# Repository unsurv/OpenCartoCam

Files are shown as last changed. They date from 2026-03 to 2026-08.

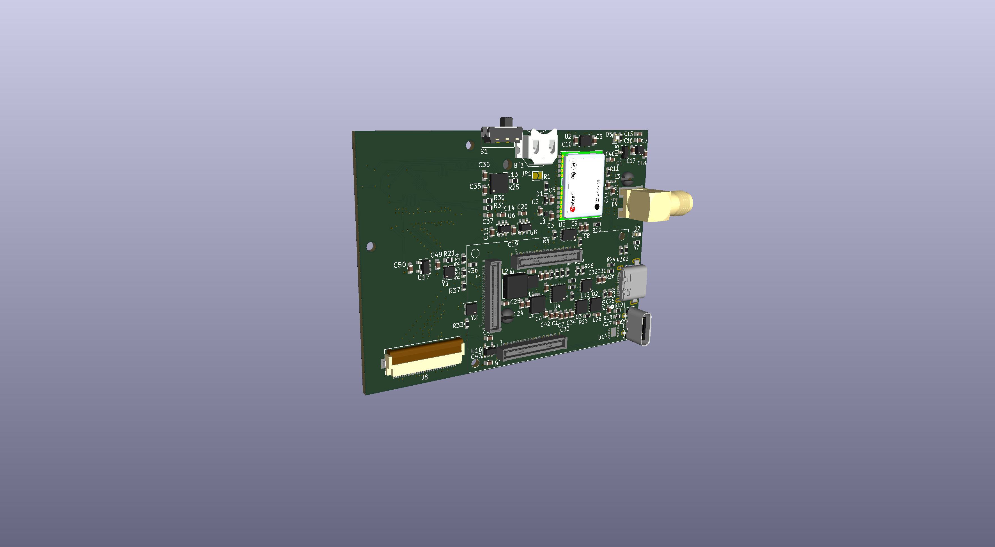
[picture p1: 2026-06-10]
docs/_static/mainboard_only.png

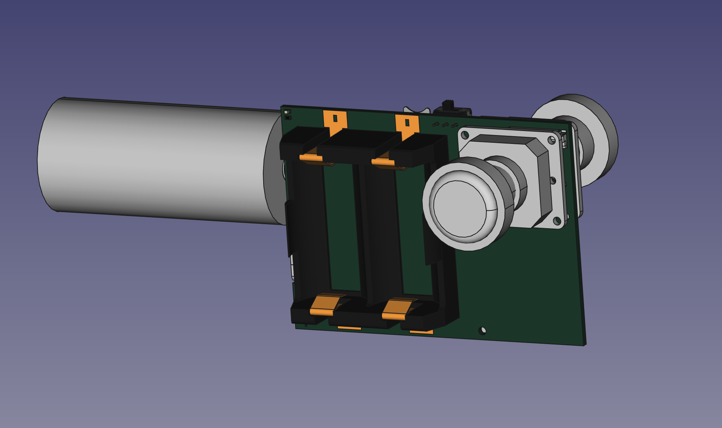
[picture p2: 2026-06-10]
docs/_static/3D_preview_back.PNG

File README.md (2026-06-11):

# OpenCartoCam

## What is it

OpenCartoCam is an open source 360-degree camera that leverages edge computing to support cartographing the world. Equipped with precise positioning systems and hardware-accelerated object detection, it enables semi-automatic mapping and categorization while maintaining a compact form factor.

## Current status

Status **in development**

- decided on SolidRun [Hailo-15-SOM](https://www.solid-run.com/hailo-15-som/) as main compute unit.
- custom designed carrier board with necessary power structure and external connectors (USB, Micro SD, SMA)
- ublox NEO-F10 GNSS receiver (L1 + L5) with passive omnidirectional antenna for good value urban performance.
- two IMX 678 (M12 lens mount) sensors with kernel support
- dead reckoning
- off the shelf [Insta360 Ace Pro 2 battery](https://store.insta360.com/en/product/ace-pro-2-battery)

## TODOs

- board evaluation
- Yocto software integration
- Sensor integration (Gyro, GNSS)

## Funding

This project is funded through [NGI0 Commons Fund](https://nlnet.nl/commonsfund), a fund established by [NLnet](https://nlnet.nl) with financial support from the European Commission's [Next Generation Internet](https://ngi.eu) program. Learn more at the [NLnet project page](https://nlnet.nl/project/OpenCartoCam).

[NLnet foundation logo](https://nlnet.nl)
[NGI Zero Logo](https://nlnet.nl/commonsfund)

## Licences

GNSS schematic partially based on [SparkFun NEO-F10N](https://github.com/sparkfun/SparkFun_u-blox_NEO-F10N)
by SparkFun Electronics, licensed under [CC BY-SA 4.0](https://creativecommons.org/licenses/by-sa/4.0/).

Modifications by Martin. Schematic is also licensed under CC BY-SA 4.0.

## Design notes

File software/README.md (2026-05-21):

# Software

## Object detection targets

- traffic signs
- traffic lights
- defib signs
- streetlamps
- zebra crossings
- manholes
- surveillance cameras

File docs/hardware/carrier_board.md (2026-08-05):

# Carrier board

The main hardware of this project is a custom carrier board for the [HAILO-15 SOM](https://www.solid-run.com/hailo-15-som/) from SolidRun. With just 47 mm x 30 mm in size it is a great basis for a custom 360° camera.

The carrier board offers the following features:

- board to board Hirose DF40 connectors matching those from the SOM
- two USB-C receptables one for USB PD 9V3A and the other exposing a shell to the HAILO-SOM.
- [ublox F10-N](https://www.u-blox.com/en/product/neo-f10n-module) multiband GNSS receiver with L5 reception to improve urban performance.
- battery and system power management (see[power management](./power.md))

``` {image} _static/3D_preview_front.PNG

```

``` {image} _static/3D_preview_back.PNG

```

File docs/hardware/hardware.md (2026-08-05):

# Hardware

``` {toctree}
:glob:

./*
```

All hardware is developed using open toolchains:

- PCB -> KiCad
- 3D design -> FreeCAD

## Images

``` {image} _static/mainboard_only.png

```

``` {image} _static/schematic.PNG

```

``` {image} _static/PCB_view.PNG

```

``` {image} _static/3D_preview_front.PNG

```

``` {image} _static/3D_preview_back.PNG

```

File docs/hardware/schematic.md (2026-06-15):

# PCB Schematic

The schematic can be found [here](https://github.com/unsurv/OpenCartoCam/tree/main/hardware/pcb/board/mainboard) as part of a KiCad project.

[Schematic PDF](./_static/mainboard.pdf)

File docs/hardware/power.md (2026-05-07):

# Power management

## Battery management

## 5V rail

## 3V3 rail

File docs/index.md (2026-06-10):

# OpenCartoCam

``` {toctree}
:hidden:
:glob:

hardware/hardware
grant/grant
```

## What is it

OpenCartoCam is an open source 360-degree camera that leverages edge computing to support cartographing the world. Equipped with precise positioning systems and hardware-accelerated object detection, it enables semi-automatic mapping and categorization while maintaining a compact form factor.

## Current status

Status **in development**

- decided on SolidRun [Hailo-15-SOM](https://www.solid-run.com/hailo-15-som/) as main compute unit.
- custom designed carrier board with necessary power structure and external connectors (USB, Micro SD, SMA)
- ublox NEO-F10 GNSS receiver (L1 + L5) with passive omnidirectional antenna for good value urban performance.
- two IMX 678 (M12 lens mount) sensors with kernel support
- dead reckoning
- off the shelf [Insta360 Ace Pro 2 battery](https://store.insta360.com/en/product/ace-pro-2-battery)

## TODOs

- carrier board evaluation
- Yocto software integration
- Sensor integration (Gyro, GNSS)
- find blade battery connector with 2 mm pitch and create daughterboard for slim battery fit

## Acknoledgements

This project is supported by [NLnet NGI0 Commons Fund](https://nlnet.nl/project/OpenCartoCam/)

## Licences

GNSS schematic partially based on [SparkFun NEO-F10N](https://github.com/sparkfun/SparkFun_u-blox_NEO-F10N)
by SparkFun Electronics, licensed under [CC BY-SA 4.0](https://creativecommons.org/licenses/by-sa/4.0/).

Modifications by Martin. Schematic is also licensed under CC BY-SA 4.0.

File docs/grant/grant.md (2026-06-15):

# nlnet grant

Initial work of this project has been supported by a grant from [nlnet](https://nlnet.nl/project/OpenCartoCam/)

This documents is used to track milestones.

## Hardware Development

Development of the physical systems, from PCB design to camera integration and sensor support, including 3D prototyping.

- buy devboard & setting it up (expense + work) ✅
  - bought [HAILO-15 dev board](https://www.solid-run.com/embedded-industrial-iot/hummingboard-hailo-15-aiot-sbc/)
- Daughterboard connection present ✅
  - see [img](#carrier-board-connection)
- Power management ✅
  - see lefthand side of [schematic](#schematic)
  - see center area of [PCB](#pcb-view)
- Battery support added ✅
  - see [PCB backside](#3d-preview-back)
  - see [BQ25606 schematic](#schematic)
- External connections (USB, antenna, camera) ✅
  - see [3D view front](#3d-preview-front)
  - see relevant parts of the [schematic](#schematic)
- PCB outline defined ✅
  - see [3D](#3d-preview-front)
- Camera connections ✅
  - see bottom right for [FPC connections](#schematic)
- Prototype assembly
- Debug connections ✅
  - see testpoints [schematic](#schematic)
  - see secondary [USB receptable](#schematic) for shell access
- SD card present ✅
  - bottom right in [schematic](#schematic)
  - see [PCB backside](#3d-preview-back)
- IMX219 driver support on development board
- Customized Yocto Linux running on dev board
- Prototype 3D case
- Sensor (GPS + gyroscope) integration
- Hardware docs
- Hardware expenses (expenses; various parts + PCB production)

## Software Development

Core software implementation, including dewarping, sensor/software integration, and privacy-aware mapping output.

- Dewarp method established
- Hardware-accelerated model running  
- Software sensor integration  
- Privacy features (face, license plate blurring)  
- Output generation
- Browser-based evaluation software developed
- OSM integration
- Custom object detection model trained and integrated
- Software docs

## Supporting Activities

Tasks supporting data collection, preparation, and documentation.

- Gathering images for retraining (work + travelling expenses)
- Image preparation (binning, labelling, scaling)

## Final release

- Beta release
- Process feedback from security audit and accessibility scan
- Final release with updated documentation

## Images

### carrier board connection

``` {image} ./_static/DF40.PNG

```

### schematic

``` {image} ../hardware/_static/schematic.PNG

```

### PCB view

``` {image} ../hardware/_static/PCB_view.PNG

```

## 3D preview front

``` {image} ../hardware/_static/3D_preview_front.PNG

```

## 3D preview back

``` {image} ../hardware/_static/3D_preview_back.PNG

```

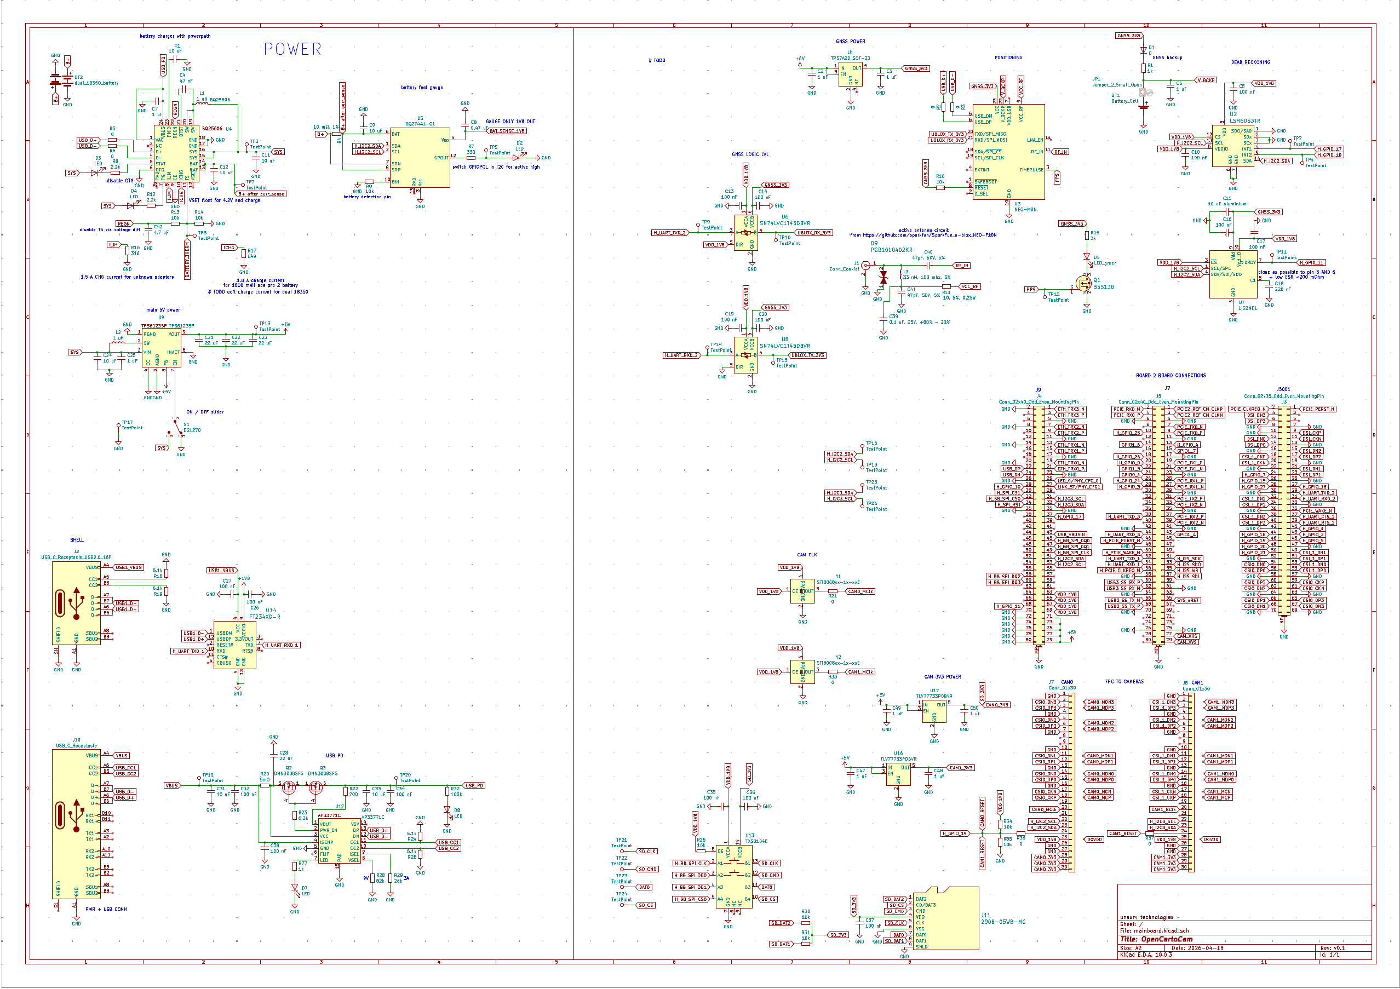
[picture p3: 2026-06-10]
docs/_static/schematic.PNG

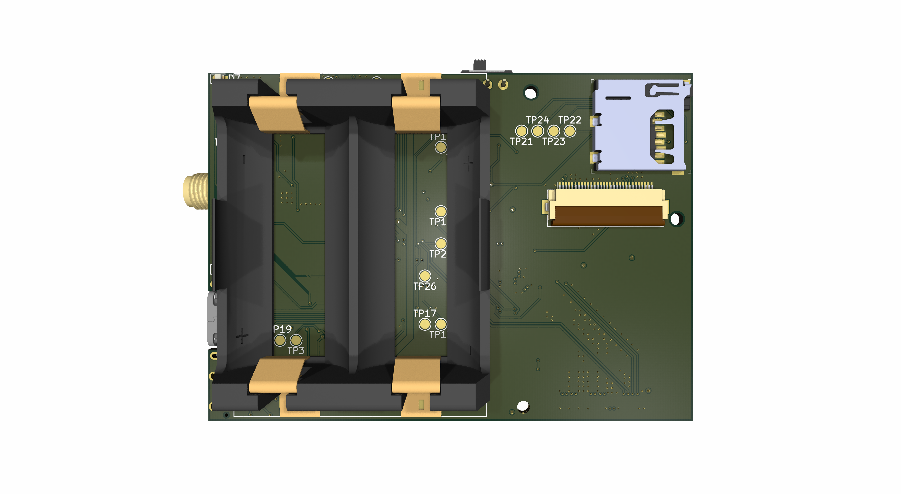
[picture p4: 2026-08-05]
hardware/pcb/board/mainboard/mainboard_raytracing_back.png

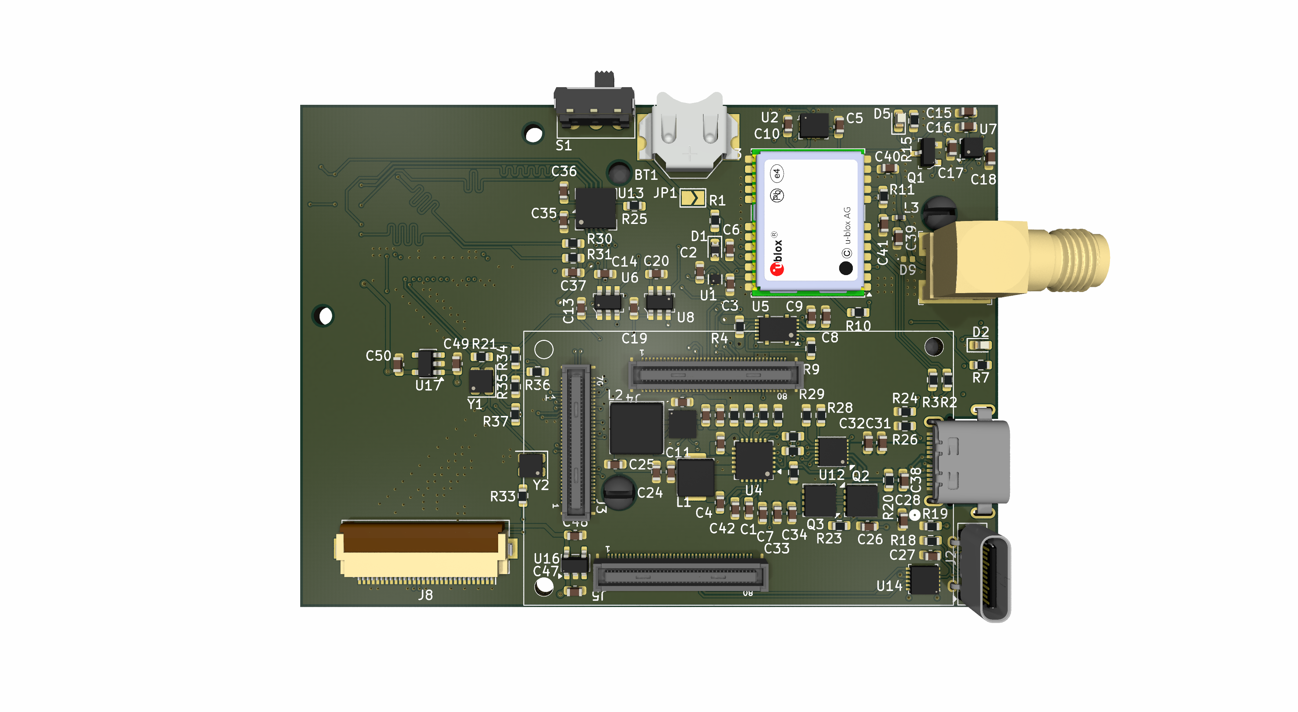
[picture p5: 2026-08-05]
hardware/pcb/board/mainboard/mainboard_raytracing.png

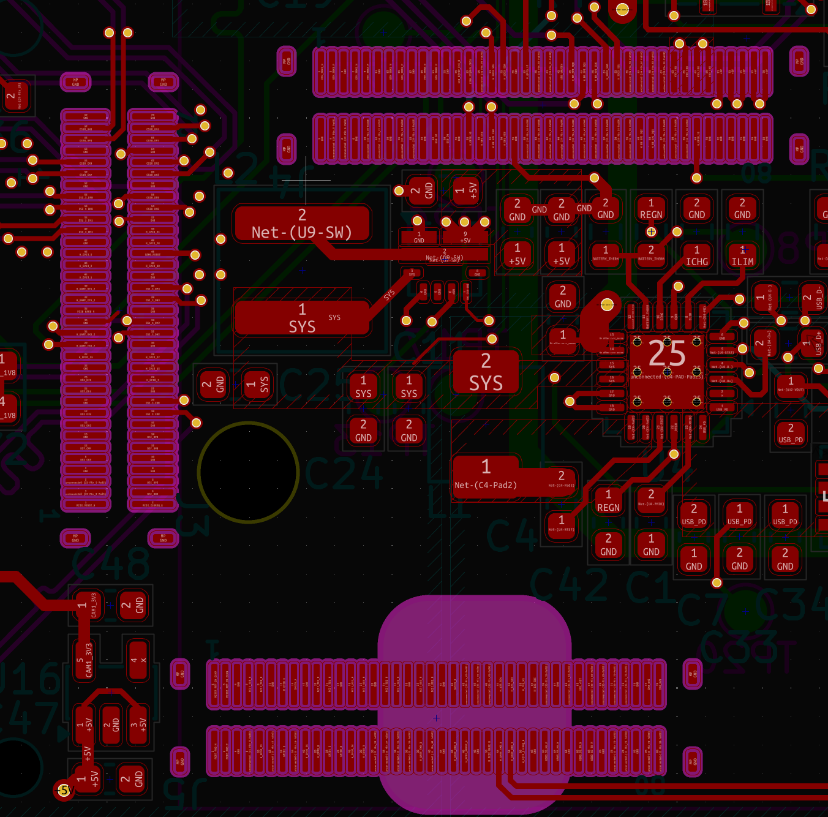
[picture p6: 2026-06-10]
docs/grant/_static/DF40.PNG

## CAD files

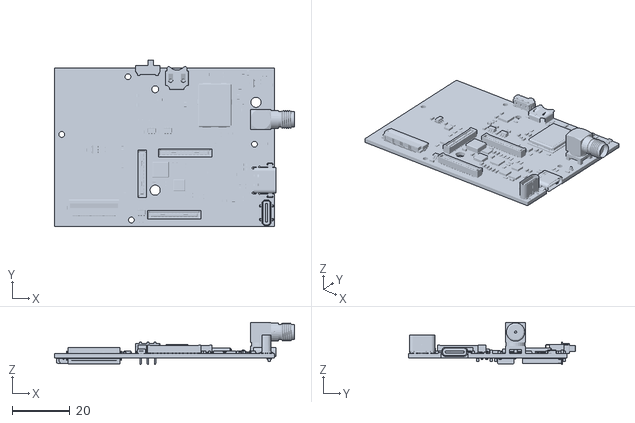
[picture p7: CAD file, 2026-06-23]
hardware/3d/camera/camera-mainboard.stl
83.3 x 57.8 x 14.8

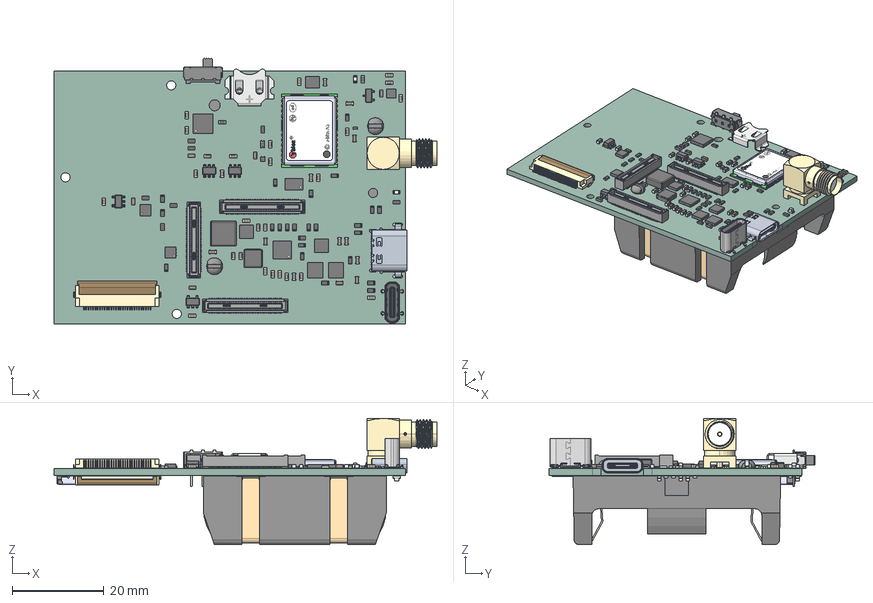
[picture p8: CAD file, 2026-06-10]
hardware/pcb/board/mainboard/mainboard.step
83.3 x 57.8 x 27.4 mm
R_0603_1608Metric x 37
DFN-12-1EP_3x3mm_P0.45mm_EP1.65x2.38mm
C_0603_1608Metric x 44
SOT-23-5 x 2
TDFN_6_1EP_25x25mm_P065mm_EP13x2mm x 2
L_0402_1005Metric
lock x 2
pins x 2
DF40HC(3.0)-80DS-0.4V x 2
LED_0603_1608Metric x 6
SOT-23-3
L_Changjiang_FNR4012S
EG1270
Texas_S_PDSO_N12
CASE
SOT-23-6 x 2
CONSMA002-SMD-G
LGA_14_3x25mm_P05mm_LayoutBorder3x4y
Diodes-PowerDI3333-8 x 2
Texas_S_PVQFN_N14
NEO_PCB
Shield_NEO
u-blox_NEO_label
QFN-24-1EP_4x4mm_Pitch0.5mm x 2
DFN_4_1EP_1x1mm_P065mm_EP05x05mm
LGA_12_2x2mm_P05mm
L_Coilcraft_XAL5020-XXX
D_0603
DFN_14_1EP_3x3mm_Pitch04mm
2908-05WB-MG
mainboard_PCB

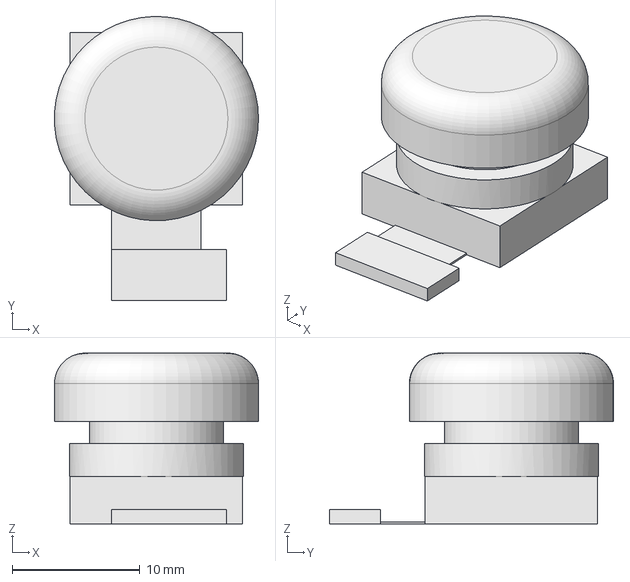
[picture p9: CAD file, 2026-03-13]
hardware/3d/IMX219/IMX219_fisheye.FCStd
16.0 x 22.2 x 13.4 mm

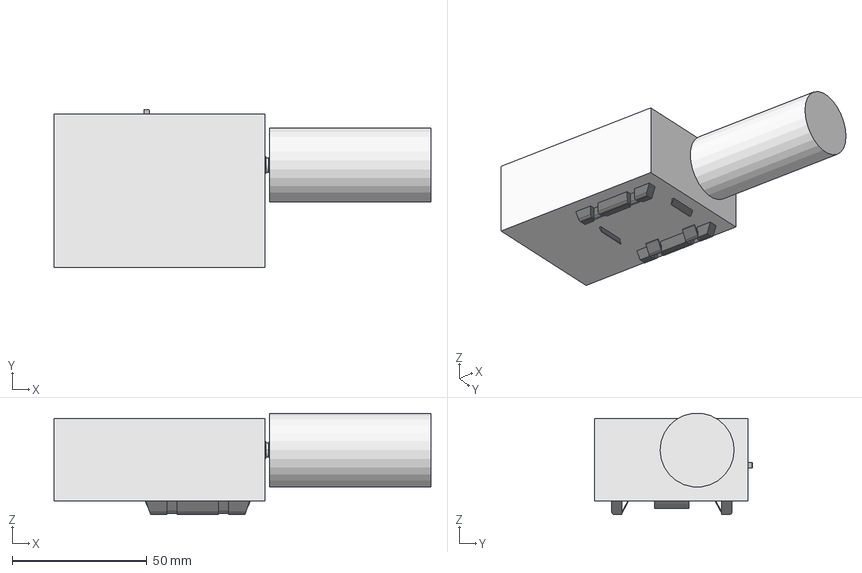
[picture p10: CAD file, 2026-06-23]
hardware/3d/camera/camera.FCStd
140.0 x 58.8 x 37.6 mm
GNSS_helical
HAILO15_SOM
front_case
R_0603_1608Metric
DFN-12-1EP_3x3mm_P0.45mm_EP1.65x2.38mm
C_0603_1608Metric
C_0603_1608Metric002
SOT-23-5
R_0603_1608Metric002
C_0603_1608Metric004
C_0603_1608Metric006
R_0603_1608Metric004
R_0603_1608Metric006
R_0603_1608Metric008
R_0603_1608Metric010
C_0603_1608Metric008
R_0603_1608Metric012
R_0603_1608Metric014
R_0603_1608Metric016
TDFN_6_1EP_25x25mm_P065mm_EP13x2mm
C_0603_1608Metric010
C_0603_1608Metric012
C_0603_1608Metric014
L_0402_1005Metric
R_0603_1608Metric018
C_0603_1608Metric016
C_0603_1608Metric018
lock
pins
C_0603_1608Metric020
C_0603_1608Metric022
R_0603_1608Metric020
DF40HC(3.0)-80DS-0.4V
LED_0603_1608Metric
C_0603_1608Metric024
C_0603_1608Metric026
R_0603_1608Metric022
SOT-23-3
R_0603_1608Metric024
C_0603_1608Metric028
L_Changjiang_FNR4012S
C_0603_1608Metric030
C_0603_1608Metric032
EG1270
Texas_S_PDSO_N12
R_0603_1608Metric026
C_0603_1608Metric034
C_0603_1608Metric036
C_0603_1608Metric038
CASE
R_0603_1608Metric028
DF40HC(3.0)-80DS-0.4V001
R_0603_1608Metric030
R_0603_1608Metric032
R_0603_1608Metric034
C_0603_1608Metric040
C_0603_1608Metric042
SOT-23-6
C_0603_1608Metric044
R_0603_1608Metric036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

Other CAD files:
hardware/3d/IMX219/IMX219_fisheye.stl

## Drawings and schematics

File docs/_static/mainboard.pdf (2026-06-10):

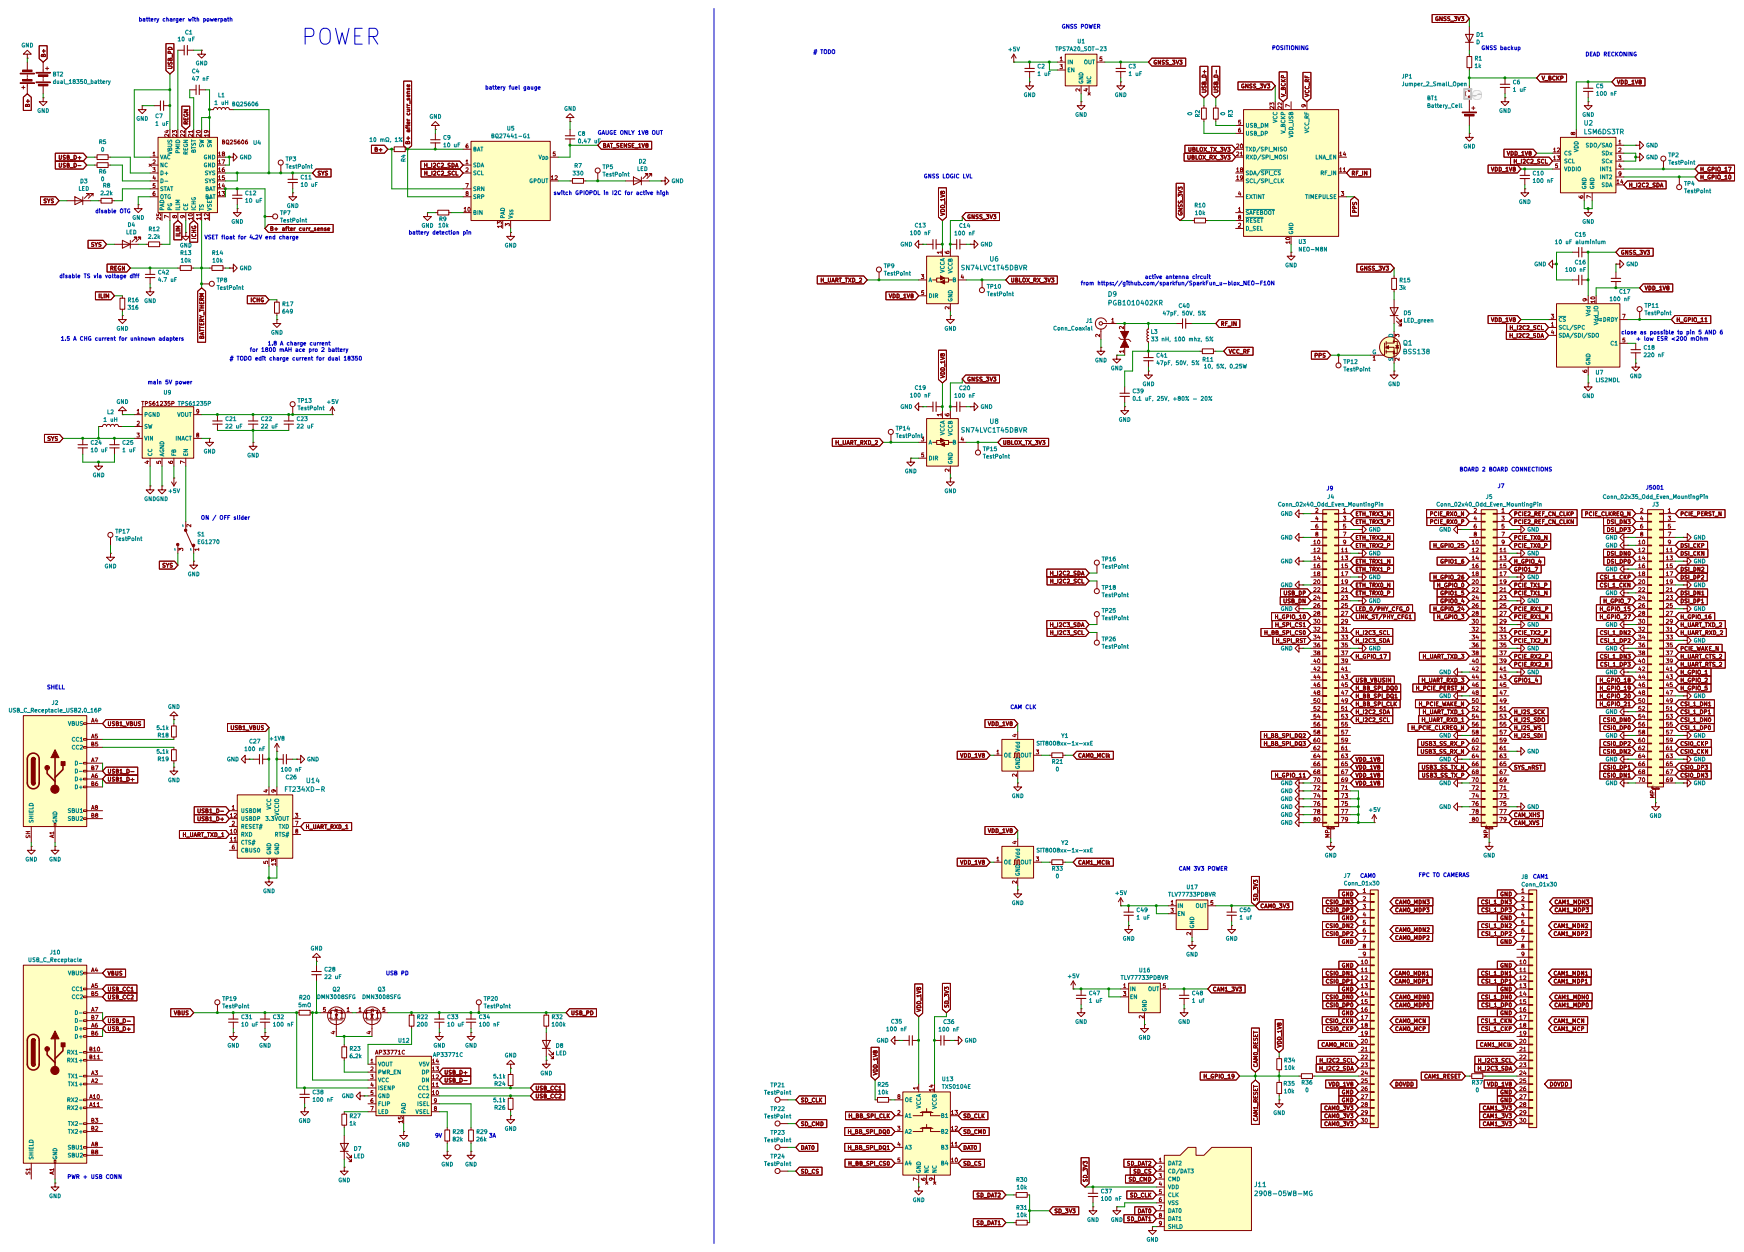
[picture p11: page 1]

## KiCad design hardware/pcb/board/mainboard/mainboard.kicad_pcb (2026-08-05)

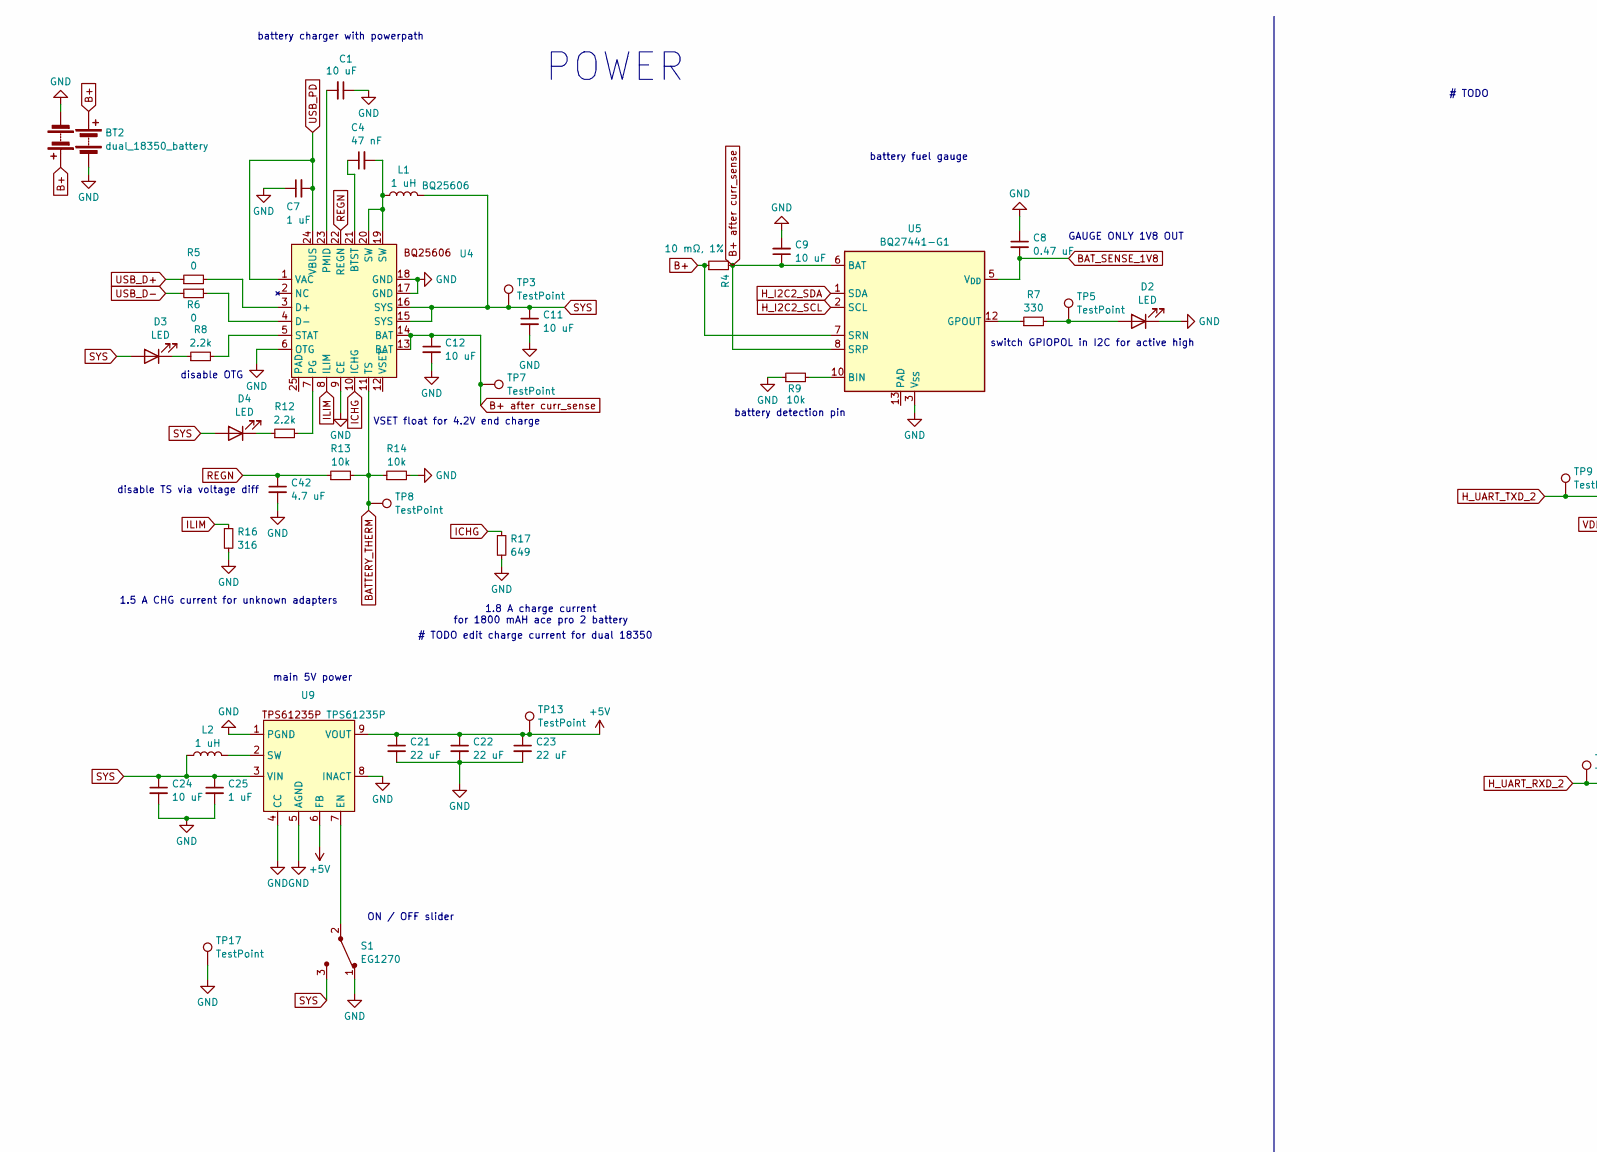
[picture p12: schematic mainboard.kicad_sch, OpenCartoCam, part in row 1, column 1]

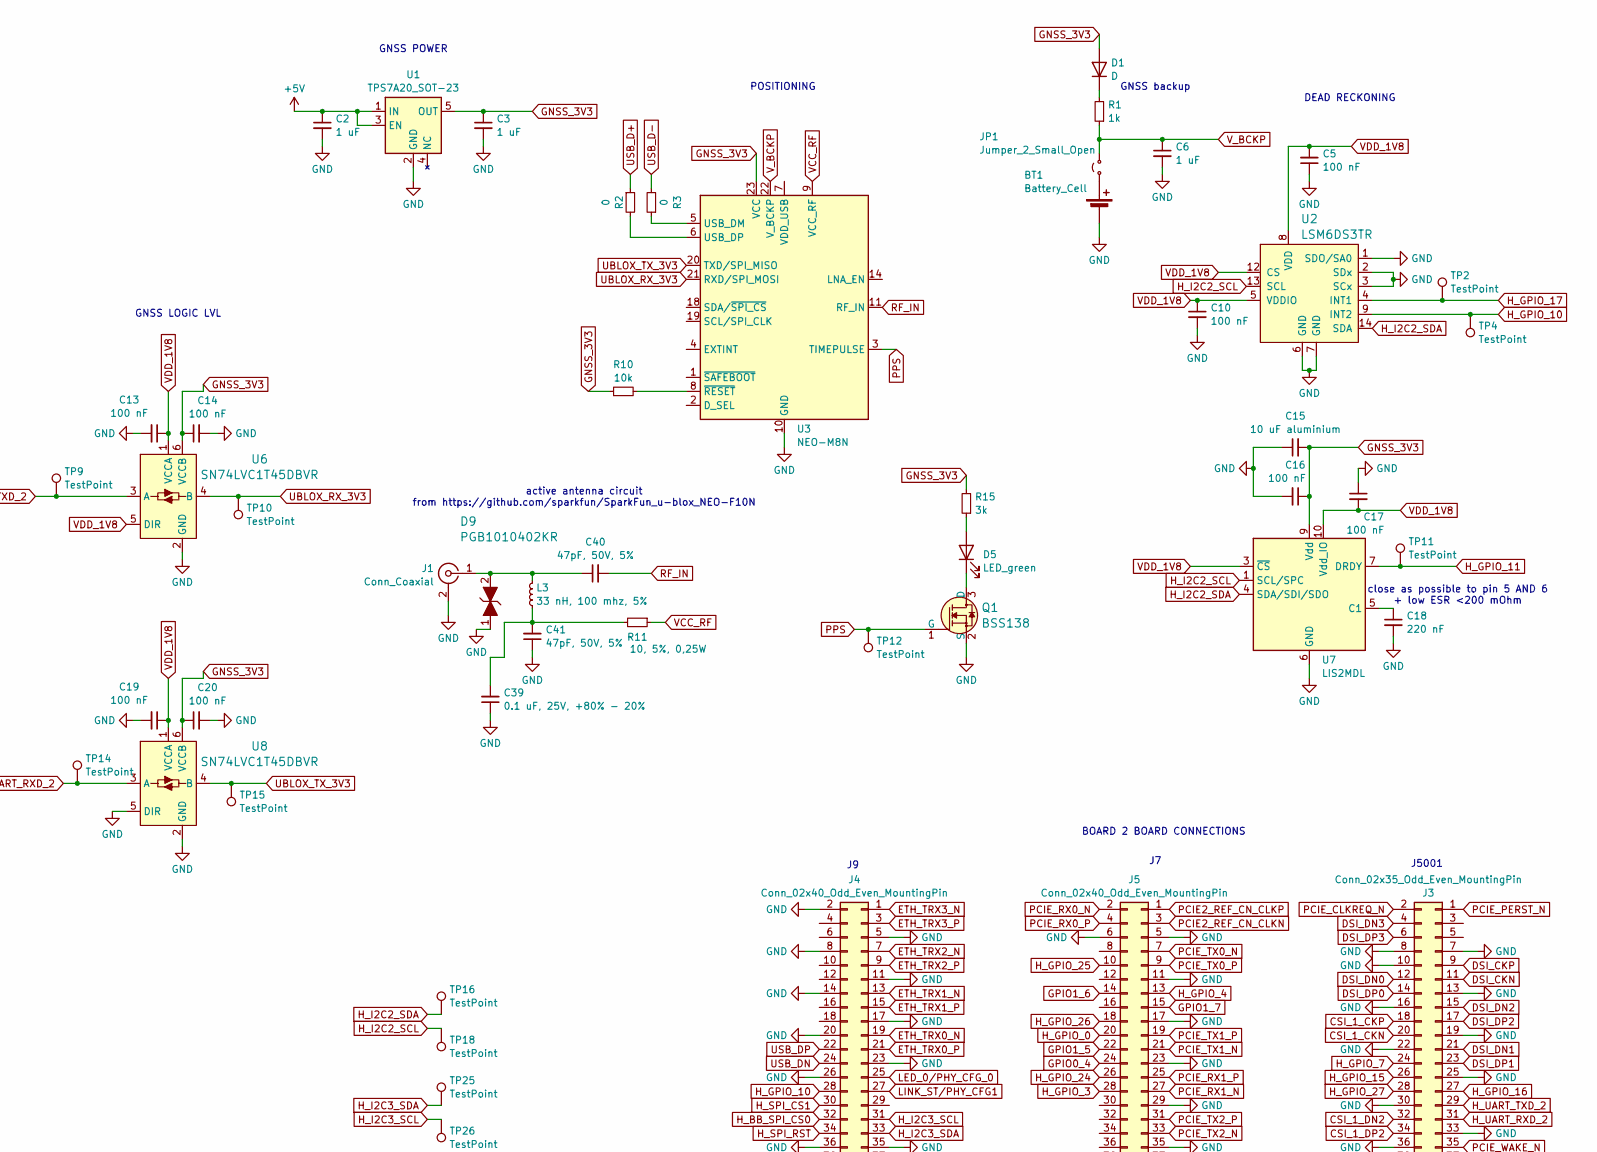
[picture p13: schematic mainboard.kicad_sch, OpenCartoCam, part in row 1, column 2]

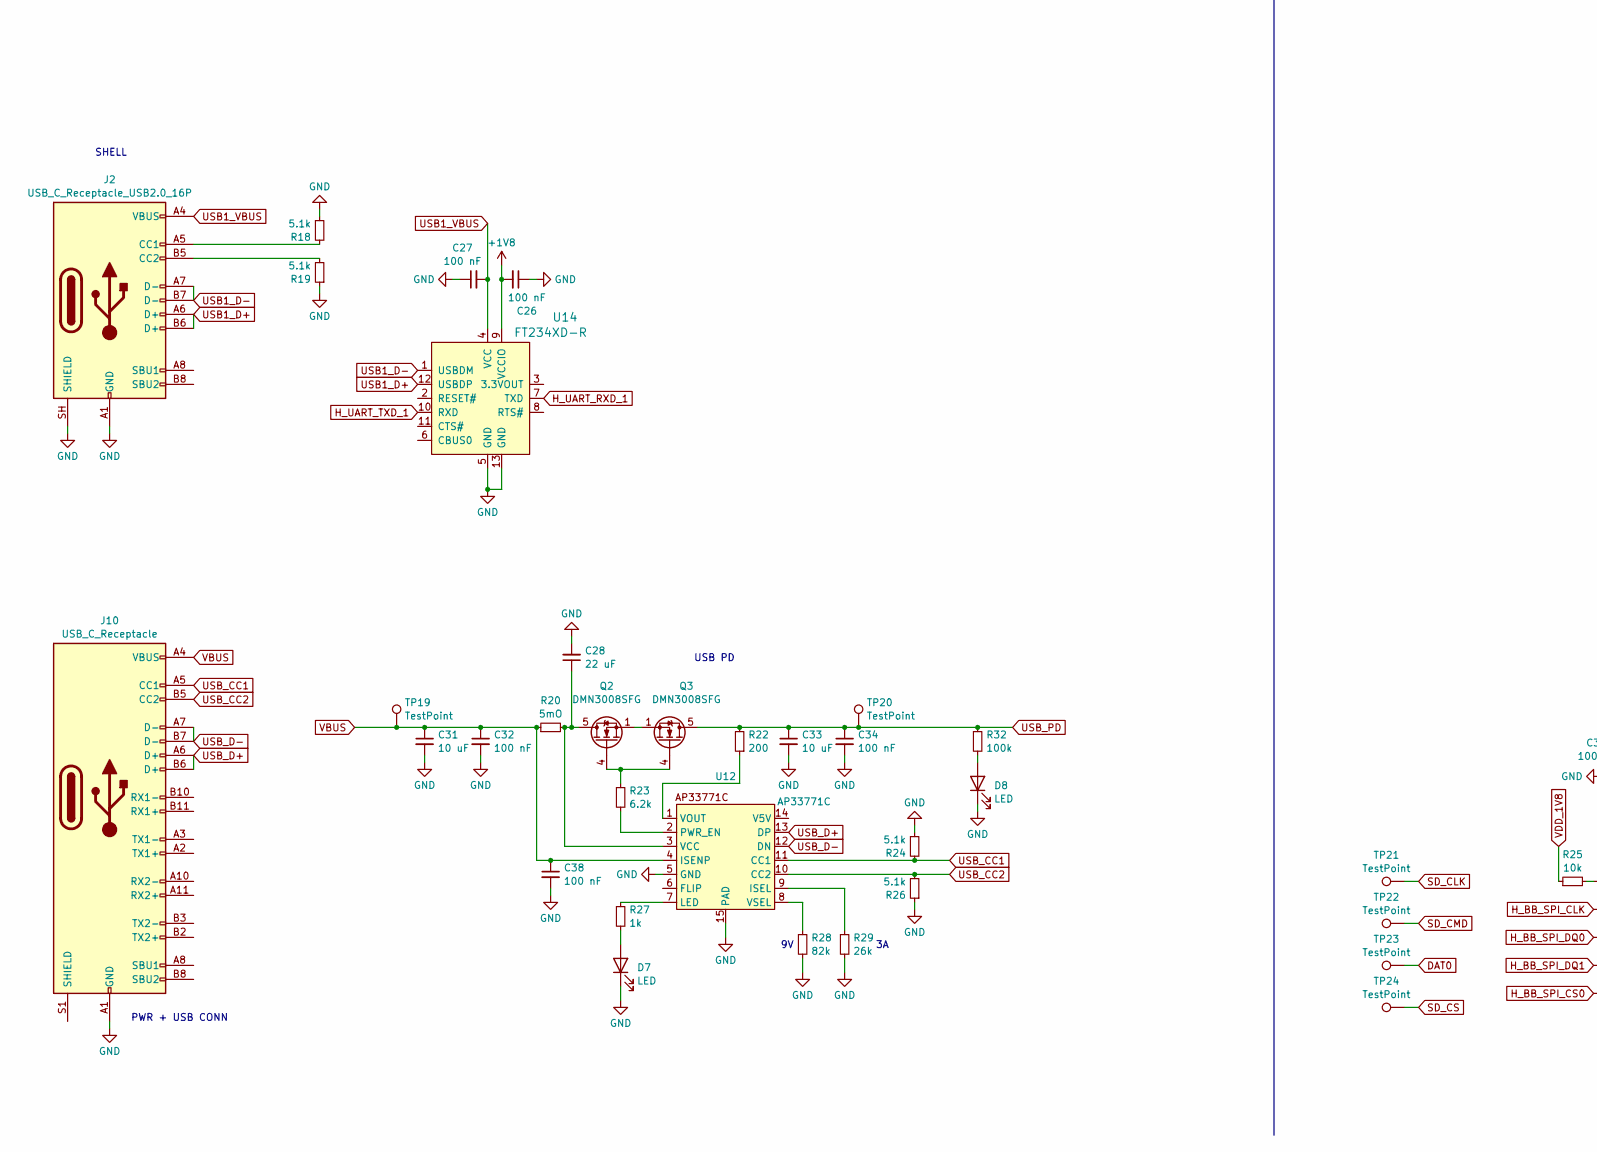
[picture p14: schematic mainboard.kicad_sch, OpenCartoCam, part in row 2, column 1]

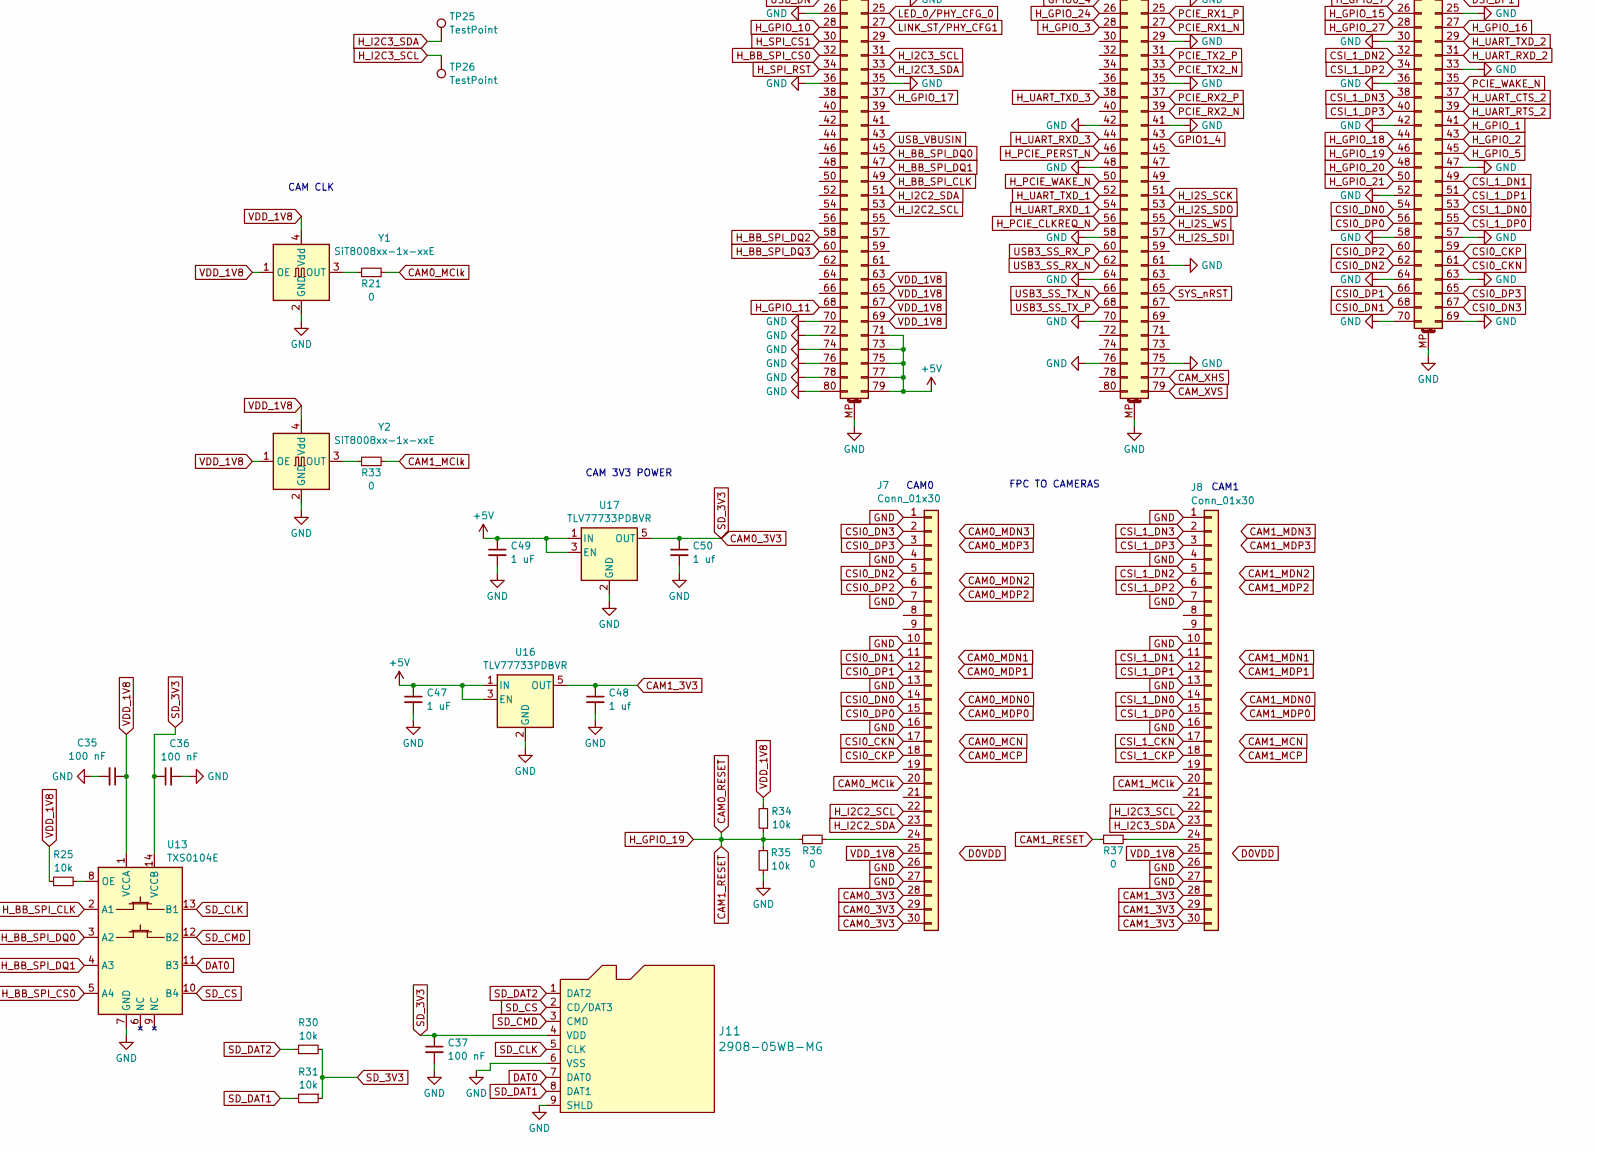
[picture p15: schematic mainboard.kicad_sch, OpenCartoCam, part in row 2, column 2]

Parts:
BT1: Battery_Cell; BatteryHolder_Keystone_2998_1x6.8mm
BT2: dual_18350_battery; keystone_dual_18350
C1, C9, C11, C12, C24, C31, C33: 10 uF; C_0603_1608Metric
C2, C3, C6, C7, C25, C47, C49: 1 uF; C_0603_1608Metric
C4: 47 nF; C_0603_1608Metric
C5, C10, C13, C14, C16, C17, C19, C20, C26, C27, C32, C34, C35, C36, C37, C38: 100 nF; C_0603_1608Metric
C8: 0.47 uF; C_0603_1608Metric
C15: 10 uF aluminium; C_0603_1608Metric
C18: 220 nF; C_0603_1608Metric
C21, C22, C23, C28: 22 uF; C_0603_1608Metric
C39: 0.1 uF, 25V, +80% - 20%; C_0603_1608Metric
C40, C41: 47pF, 50V, 5%; C_0603_1608Metric
C42: 4.7 uF; C_0603_1608Metric
C48, C50: 1 uf; C_0603_1608Metric
D1: D; D_0603_1608Metric
D2, D3, D4, D7, D8: LED; LED_0603_1608Metric
D5: LED_green; LED_0603_1608Metric
D9: PGB1010402KR; D_0402_1005Metric; MPN PGB1010603MR; Digi-Key_PN F2594CT-ND
J1: Conn_Coaxial; RF_SMA_Receptical_Vertical_CONSMA002-SMD-G
J2: USB_C_Receptacle_USB2.0_16P; 2171820001_USB_C_MOLEX
J3: Conn_02x35_Odd_Even_MountingPin; DF40_3.0_70
J4, J5: Conn_02x40_Odd_Even_MountingPin; DF40_3.0_80
J7, J8: Conn_01x30; Hirose_FH12-30S-0.5SH_1x30-1MP_P0.50mm_Horizontal
J10: USB_C_Receptacle; USB_C_CONN_1054550101_MOL
J11: 2908-05WB-MG; MicroSD_2908-05WB-MG; MPN 2908-05WB-MG; Digi-Key_PN 3M5607CT-ND
JP1: Jumper_2_Small_Open; SolderJumper-2_P1.3mm_Open_TrianglePad1.0x1.5mm
L1: 1 uH; Inductor_Wuerth_74437321010
L2: 1 uH; L_Coilcraft_XAL5020-XXX
L3: 33 nH, 100 mhz, 5%; L_0402_1005Metric
Q1: BSS138; SOT-23-3; MPN BSS138; Digi-Key_PN BSS138CT-ND
Q2, Q3: DMN3008SFG; Diodes_PowerDI3333-8
R1, R27: 1k; R_0603_1608Metric
R2, R3, R5, R6, R21, R33, R36, R37: 0; R_0603_1608Metric
R4: 10 mΩ, 1%; R_0603_1608Metric
R7: 330; R_0603_1608Metric
R8, R12: 2.2k; R_0603_1608Metric
R9, R10, R13, R14, R25, R30, R31, R34, R35: 10k; R_0603_1608Metric
R11: 10, 5%, 0,25W; R_0603_1608Metric
R15: 3k; R_0603_1608Metric
R16: 316; R_0603_1608Metric
R17: 649; R_0603_1608Metric
R18, R19, R24, R26: 5.1k; R_0603_1608Metric
R20: 5mO; R_0603_1608Metric
R22: 200; R_0603_1608Metric
R23: 6.2k; R_0603_1608Metric
R28: 82k; R_0603_1608Metric
R29: 26k; R_0603_1608Metric
R32: 100k; R_0603_1608Metric
S1: EG1270; EG1270 switch; MPN EG1218; Digi-Key_PN EG1903-ND
TP2, TP3, TP4, TP5, TP7, TP8, TP9, TP10, TP11, TP12, TP13, TP14, TP15, TP16, TP17, TP18, TP19, TP20, TP21, TP22, TP23, TP24, TP25, TP26: TestPoint; TestPoint_Pad_D1.5mm
U1: TPS7A20_SOT-23; Texas_X2SON-4_1x1mm_P0.65mm
U2: LSM6DS3TR; LGA-14L_2.5x3mm__LSM6DS3; MPN LSM6DS3TR; Digi-Key_PN 497-15383-1-ND
U3: NEO-M8N; ublox_NEO
U4: BQ25606; HVQFN-24-1EP_4x4mm_P0.5mm_EP2.6x2.6mm_0.25drill_ThermalVias
U5: BQ27441-G1; Texas_S-PDSO-N12
U6, U8: SN74LVC1T45DBVR; SOT-23-6; MPN SN74LVC1T45DBVR; Digi-Key_PN 296-16843-1-ND
U7: LIS2MDL; LGA-12_2x2mm_P0.5mm
U9: TPS61235P; cursed_TI-QFN9_TPS61235
U12: AP33771C; DFN-14-1EP_3x3mm_P0.4mm_EP1.80x2.70mm
U13: TXS0104E; Texas_S-PVQFN-N14
U14: FT234XD-R; DFN-12-1EP_3x3mm; MPN FT234XD-R; Digi-Key_PN 768-1178-1-ND
U16, U17: TLV77733PDBVR; SOT-23-5
Y1, Y2: SiT8008xx-1x-xxE; Oscillator_SMD_SiT_PQFN-4Pin_2.5x2.0mm

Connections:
+1V8: C26.2, U14.9 (VCCIO)
+5V: C2.1, C21.1, C22.1, C23.1, C47.1, C49.1, J4.71, J4.73, J4.75, J4.77, J4.79, TP13.1 (1_1), U1.1 (IN), U1.3 (EN), U9.6 (FB), U9.9 (VOUT), U16.1 (IN), U16.3 (EN), U17.1 (IN), U17.3 (EN)
B+: BT2.1 (+), R4.1, U5.7 (SRN)
B+ after curr_sense: C9.1, C12.1, R4.2, TP7.1 (1_1), U4.13 (BAT), U4.14 (BAT), U5.6 (BAT), U5.8 (SRP)
BATTERY_THERM: R13.2, R14.1, TP8.1 (1_1), U4.11 (TS)
BAT_SENSE_1V8: C8.2, U5.5 (V_{DD})
CAM0_3V3: C36.1, C37.1, C50.1, J7.28, J7.29, J7.30, J11.4 (VDD), R30.2, R31.1, U13.14 (VCCB), U17.5 (OUT)
CAM0_MClk: J7.20, R21.2
CAM0_RESET: J3.46, R34.1, R35.2, R36.1, R37.1
CAM1_3V3: C48.1, J8.28, J8.29, J8.30, U16.5 (OUT)
CAM1_MClk: J8.20, R33.2
CAM_XHS: J5.77
CAM_XVS: J5.79
CSI0_CKN: J3.61, J7.17
CSI0_CKP: J3.59, J7.18
CSI0_DN0: J3.54, J7.14
CSI0_DN1: J3.68, J7.11
CSI0_DN2: J3.62, J7.5
CSI0_DN3: J3.67, J7.2
CSI0_DP0: J3.56, J7.15
CSI0_DP1: J3.66, J7.12
CSI0_DP2: J3.60, J7.6
CSI0_DP3: J3.65, J7.3
CSI_1_CKN: J3.20, J8.17
CSI_1_CKP: J3.18, J8.18
CSI_1_DN0: J3.53, J8.14
CSI_1_DN1: J3.49, J8.11
CSI_1_DN2: J3.32, J8.5
CSI_1_DN3: J3.38, J8.2
CSI_1_DP0: J3.55, J8.15
CSI_1_DP1: J3.51, J8.12
CSI_1_DP2: J3.34, J8.6
CSI_1_DP3: J3.40, J8.3
DAT0: J11.7 (DAT0), TP23.1 (1_1), U13.11 (B3)
DSI_CKN: J3.11
DSI_CKP: J3.9
DSI_DN0: J3.12
DSI_DN1: J3.21
DSI_DN2: J3.15
DSI_DN3: J3.4
DSI_DP0: J3.14
DSI_DP1: J3.23
DSI_DP2: J3.17
DSI_DP3: J3.6
ETH_TRX0_N: J4.19
ETH_TRX0_P: J4.21
ETH_TRX1_N: J4.13
ETH_TRX1_P: J4.15
ETH_TRX2_N: J4.7
ETH_TRX2_P: J4.9
ETH_TRX3_N: J4.1
ETH_TRX3_P: J4.3
GND: BT1.2 (-), BT2.2 (-), C1.1, C2.2, C3.2, C5.1, C6.2, C7.1, C8.1, C9.2, C10.2, C11.2, C12.2, C13.2, C14.2, C15.1, C16.2, C17.1, C18.2, C19.2, C20.2, C21.2, C22.2, C23.2, C24.2, C25.2, C26.1, C27.1, C28.2, C31.2, C32.2, C33.2, C34.2, C35.2, C36.2, C37.2, C38.2, C39.1, C41.1, C42.2, C47.2, C48.2, C49.2, C50.2, D2.1 (K), D7.1 (K), D8.1 (K), D9.1, J1.2 (Ext), J2.A1 (GND), J2.A12 (GND), J2.B1 (GND), J2.B12 (GND), J2.SH (SHIELD), J3.7, J3.8, J3.10, J3.13, J3.16, J3.19, J3.22, J3.25, J3.30, J3.33, J3.36, J3.42, J3.47, J3.52, J3.57, J3.58, J3.63, J3.64, J3.69, J3.70, J3.MP (MountPin), J4.2, J4.5, J4.8, J4.11, J4.14, J4.17, J4.20, J4.23, J4.26, J4.35, J4.36, J4.70, J4.72, J4.74, J4.76, J4.78, J4.80, J4.MP (MountPin), J5.5, J5.6, J5.11, J5.17, J5.23, J5.29, J5.35, J5.41, J5.42, J5.48, J5.58, J5.61, J5.64, J5.70, J5.75, J5.76, J5.MP (MountPin), J7.1, J7.4, J7.7, J7.10, J7.13, J7.16, J7.26, J7.27, J8.1, J8.4, J8.7, J8.10, J8.13, J8.16, J8.26, J8.27, J10.A1 (GND), J10.A12 (GND), J10.B1 (GND), J10.B12 (GND), J11.6 (VSS), J11.9 (SHLD), Q1.2 (S), R9.1, R14.2, R16.2, R17.2, R18.1, R19.1, R24.1, R26.1, R28.2, R29.2, R35.1, S1.1, TP17.1 (1_1), U1.2 (GND), U2.1 (SDO/SA0), U2.2 (SDx), U2.3 (SCx), U2.6 (GND), U2.7 (GND), U3.10 (GND), U3.12 (GND), U3.13 (GND), U3.24 (GND), U4.6 (OTG), U4.9 (CE), U4.17 (GND), U4.18 (GND), U5.3 (V_{SS}), U6.2 (GND), U7.6 (GND), U7.8 (GND), U8.2 (GND), U8.5 (DIR), U9.1 (PGND), U9.4 (CC), U9.5 (AGND), U9.8 (INACT), U12.5 (GND), U12.15 (PAD), U13.7 (GND), U14.5 (GND), U14.13 (GND), U16.2 (GND), U17.2 (GND), Y1.2 (GND), Y2.2 (GND)
GNSS_3V3: C3.1, C14.1, C15.2, C16.1, C20.1, D1.2 (A), R10.1, R15.2, U1.5 (OUT), U3.23 (VCC), U6.6 (VCCB), U7.9 (Vdd), U8.6 (VCCB)
GPIO0_4: J5.24
GPIO1_4: J5.43
GPIO1_5: J5.22
GPIO1_6: J5.14
GPIO1_7: J5.15
H_BB_SPI_CLK: J4.49, U13.2 (A1)
H_BB_SPI_CS0: J4.32, U13.5 (A4)
H_BB_SPI_DQ0: J4.45, U13.3 (A2)
H_BB_SPI_DQ1: J4.47, U13.4 (A3)
H_BB_SPI_DQ2: J4.58
H_BB_SPI_DQ3: J4.60
H_GPIO_0: J5.20
H_GPIO_1: J3.41
H_GPIO_2: J3.43
H_GPIO_3: J5.28
H_GPIO_4: J5.13
H_GPIO_5: J3.45
H_GPIO_7: J3.24
H_GPIO_10: J4.28, TP4.1 (1_1), U2.9 (INT2)
H_GPIO_11: J4.68, TP11.1 (1_1), U7.7 (DRDY)
H_GPIO_15: J3.26
H_GPIO_16: J3.27
H_GPIO_17: J4.37, TP2.1 (1_1), U2.4 (INT1)
H_GPIO_18: J3.44
H_GPIO_20: J3.48
H_GPIO_21: J3.50
H_GPIO_24: J5.26
H_GPIO_25: J5.10
H_GPIO_26: J5.18
H_GPIO_27: J3.28
H_I2C2_SCL: J4.53, J7.22, TP18.1 (1_1), U2.13 (SCL), U5.2 (SCL), U7.1 (SCL/SPC)
H_I2C2_SDA: J4.51, J7.23, TP16.1 (1_1), U2.14 (SDA), U5.1 (SDA), U7.4 (SDA/SDI/SDO)
H_I2C3_SCL: J4.31, J8.22, TP26.1 (1_1)
H_I2C3_SDA: J4.33, J8.23, TP25.1 (1_1)
H_I2S_SCK: J5.51
H_I2S_SDI: J5.57
H_I2S_SDO: J5.53
H_I2S_WS: J5.55
H_PCIE_CLKREQ_N: J5.56
H_PCIE_PERST_N: J5.46
H_PCIE_WAKE_N: J5.50
H_SPI_CS1: J4.30
H_SPI_RST: J4.34
H_UART_CTS_2: J3.37
H_UART_RTS_2: J3.39
H_UART_RXD_1: J5.54, U14.7 (TXD)
H_UART_RXD_2: J3.31, TP14.1 (1_1), U8.3 (A)
H_UART_RXD_3: J5.44
H_UART_TXD_1: J5.52, U14.10 (RXD)
H_UART_TXD_2: J3.29, TP9.1 (1_1), U6.3 (A)
H_UART_TXD_3: J5.38
ICHG: R17.1, U4.10 (ICHG)
ILIM: R16.1, U4.8 (ILIM)
LED_0/PHY_CFG_0: J4.25
LINK_ST/PHY_CFG1: J4.27
unnamed: BT1.1 (+), JP1.1 (A)
unnamed: C4.2, L1.1, U4.19 (SW), U4.20 (SW)
unnamed: C39.2, C41.2, L3.1, R11.2
unnamed: D1.1 (K), R1.2
unnamed: D2.2 (A), R7.2, TP5.1 (1_1)
unnamed: D3.1 (K), R8.1
unnamed: D4.1 (K), R12.1
unnamed: D5.2 (A), R15.1
unnamed: D5.1 (K), Q1.3 (D)
unnamed: D7.2 (A), R27.2
unnamed: D8.2 (A), R32.2
unnamed: C40.1, D9.2, J1.1 (In), L3.2
unnamed: J2.A5 (CC1), R18.2
unnamed: J2.B5 (CC2), R19.2
unnamed: J7.24, R36.2
unnamed: J8.24, R37.2
unnamed: C28.1, Q2.5 (D), R20.2, U12.3 (VCC)
unnamed: Q2.4 (G), Q3.4 (G), R23.1
unnamed: Q2.1 (S), Q2.2 (S), Q2.3 (S), Q3.1 (S), Q3.2 (S), Q3.3 (S)
unnamed: R3.1, U3.5 (USB_DM)
unnamed: R2.2, U3.6 (USB_DP)
unnamed: R10.2, U3.8 (~RESET)
unnamed: C4.1, U4.21 (BTST)
unnamed: R5.2, U4.3 (D+)
unnamed: R6.1, U4.4 (D-)
unnamed: R12.2, U4.7 (PG)
unnamed: C1.2, U4.23 (PMID)
unnamed: R8.2, U4.5 (STAT)
unnamed: R9.2, U5.10 (BIN)
unnamed: R7.1, U5.12 (GPOUT)
unnamed: C18.1, U7.5 (C1)
unnamed: S1.2, U9.7 (EN)
unnamed: L2.2, U9.2 (SW)
unnamed: R29.1, U12.9 (ISEL)
unnamed: R27.1, U12.7 (LED)
unnamed: R23.2, U12.2 (PWR_EN)
unnamed: R22.1, U12.1 (VOUT)
unnamed: R28.1, U12.8 (VSEL)
unnamed: R25.2, U13.8 (OE)
unnamed: R21.1, Y1.3 (OUT)
unnamed: R33.1, Y2.3 (OUT)
PCIE2_REF_CN_CLKN: J5.3
PCIE2_REF_CN_CLKP: J5.1
PCIE_CLKREQ_N: J3.2
PCIE_PERST_N: J3.1
PCIE_RX0_N: J5.2
PCIE_RX0_P: J5.4
PCIE_RX1_N: J5.27
PCIE_RX1_P: J5.25
PCIE_RX2_N: J5.39
PCIE_RX2_P: J5.37
PCIE_TX0_N: J5.7
PCIE_TX0_P: J5.9
PCIE_TX1_N: J5.21
PCIE_TX1_P: J5.19
PCIE_TX2_N: J5.33
PCIE_TX2_P: J5.31
PCIE_WAKE_N: J3.35
PPS: Q1.1 (G), TP12.1 (1_1), U3.3 (TIMEPULSE)
REGN: C42.1, R13.1, U4.22 (REGN)
RF_IN: C40.2, U3.11 (RF_IN)
SD_CLK: J11.5 (CLK), TP21.1 (1_1), U13.13 (B1)
SD_CMD: J11.3 (CMD), TP22.1 (1_1), U13.12 (B2)
SD_CS: J11.2 (CD/DAT3), TP24.1 (1_1), U13.10 (B4)
SD_DAT1: J11.8 (DAT1), R31.2
SD_DAT2: J11.1 (DAT2), R30.1
SYS: C11.1, C24.1, C25.1, D3.2 (A), D4.2 (A), L1.2, L2.1, S1.3, TP3.1 (1_1), U4.15 (SYS), U4.16 (SYS), U9.3 (VIN)
SYS_nRST: J5.65
UBLOX_RX_3V3: TP10.1 (1_1), U3.21 (RXD/SPI_MOSI), U6.4 (B)
UBLOX_TX_3V3: TP15.1 (1_1), U3.20 (TXD/SPI_MISO), U8.4 (B)
USB1_D+: J2.A6 (D+), J2.B6 (D+), U14.12 (USBDP)
USB1_D-: J2.A7 (D-), J2.B7 (D-), U14.1 (USBDM)
USB1_VBUS: C27.2, J2.A4 (VBUS), J2.A9 (VBUS), J2.B4 (VBUS), J2.B9 (VBUS), U14.4 (VCC)
USB3_SS_RX_N: J5.62
USB3_SS_RX_P: J5.60
USB3_SS_TX_N: J5.66
USB3_SS_TX_P: J5.68
USB_CC1: J10.A5 (CC1), R24.2, U12.11 (CC1)
USB_CC2: J10.B5 (CC2), R26.2, U12.10 (CC2)
USB_D+: J10.A6 (D+), J10.B6 (D+), R2.1, R5.1, U12.13 (DP)
USB_D-: J10.A7 (D-), J10.B7 (D-), R3.2, R6.2, U12.12 (DN)
USB_DN: J4.24
USB_DP: J4.22
USB_PD: C7.2, C33.1, C34.1, Q3.5 (D), R22.2, R32.1, TP20.1 (1_1), U4.1 (VAC), U4.24 (VBUS)
USB_VBUSIN: J4.43
VBUS: C31.1, C32.1, C38.1, J10.A4 (VBUS), J10.A9 (VBUS), J10.B4 (VBUS), J10.B9 (VBUS), R20.1, TP19.1 (1_1), U12.4 (ISENP)
VCC_RF: R11.1, U3.9 (VCC_RF)
VDD_1V8: C5.2, C10.1, C13.1, C17.2, C19.1, C35.1, J4.63, J4.65, J4.67, J4.69, J7.25, J8.25, R25.1, R34.2, U2.5 (VDDIO), U2.8 (VDD), U2.12 (CS), U6.1 (VCCA), U6.5 (DIR), U7.3 (~CS), U7.10 (Vdd_IO), U8.1 (VCCA), U13.1 (VCCA), Y1.1 (OE), Y1.4 (Vdd), Y2.1 (OE), Y2.4 (Vdd)
V_BCKP: C6.1, JP1.2 (B), R1.1, U3.22 (V_BCKP)

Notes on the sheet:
BOARD 2 BOARD CONNECTIONS
ON / OFF slider
J5001
# TODO edit charge current for dual 18350
USB PD
CAM CLK
GNSS backup
battery detection pin
FPC TO CAMERAS
# TODO
CAM 3V3 POWER
battery charger with powerpath
main 5V power
PWR + USB CONN
close as possible to pin 5 AND 6 + low ESR <200 mOhm
disable OTG
GAUGE ONLY 1V8 OUT
GNSS POWER
POSITIONING
1.5 A CHG current for unknown adapters
POWER
disable TS via voltage diff
DEAD RECKONING
SHELL
CAM0
GNSS LOGIC LVL
switch GPIOPOL in I2C for active high
1.8 A charge current for 1800 mAH ace pro 2 battery
active antenna circuit from https://github.com/sparkfun/SparkFun_u-blox_NEO-F10N
battery fuel gauge
CAM1
VSET float for 4.2V end charge

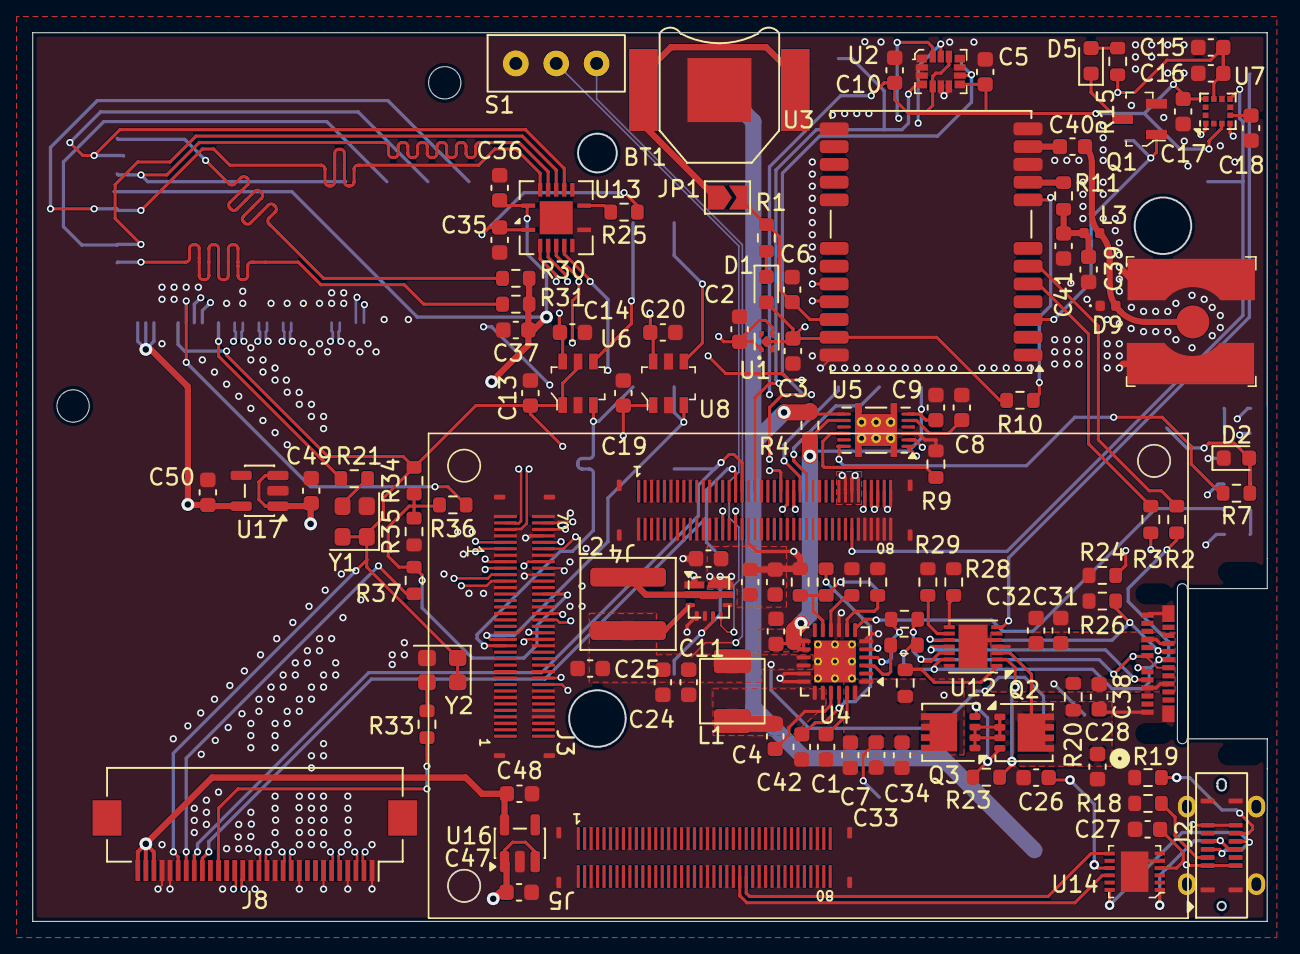
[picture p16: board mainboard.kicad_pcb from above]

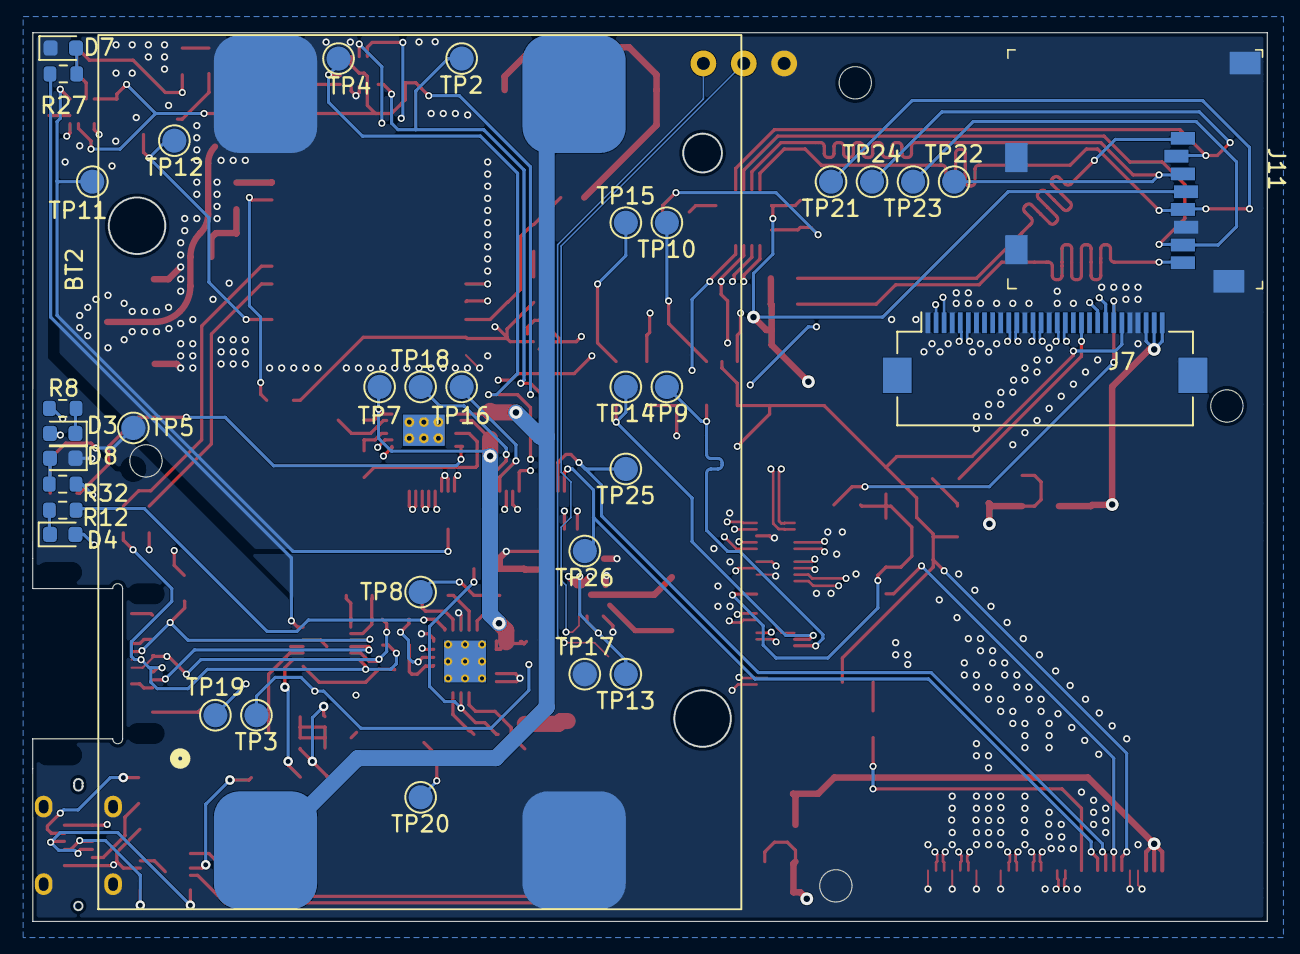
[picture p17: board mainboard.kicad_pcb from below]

Board: 6 copper layers, 76.4 x 55.0 mm, 148 parts (35 on the bottom side), 115 nets.

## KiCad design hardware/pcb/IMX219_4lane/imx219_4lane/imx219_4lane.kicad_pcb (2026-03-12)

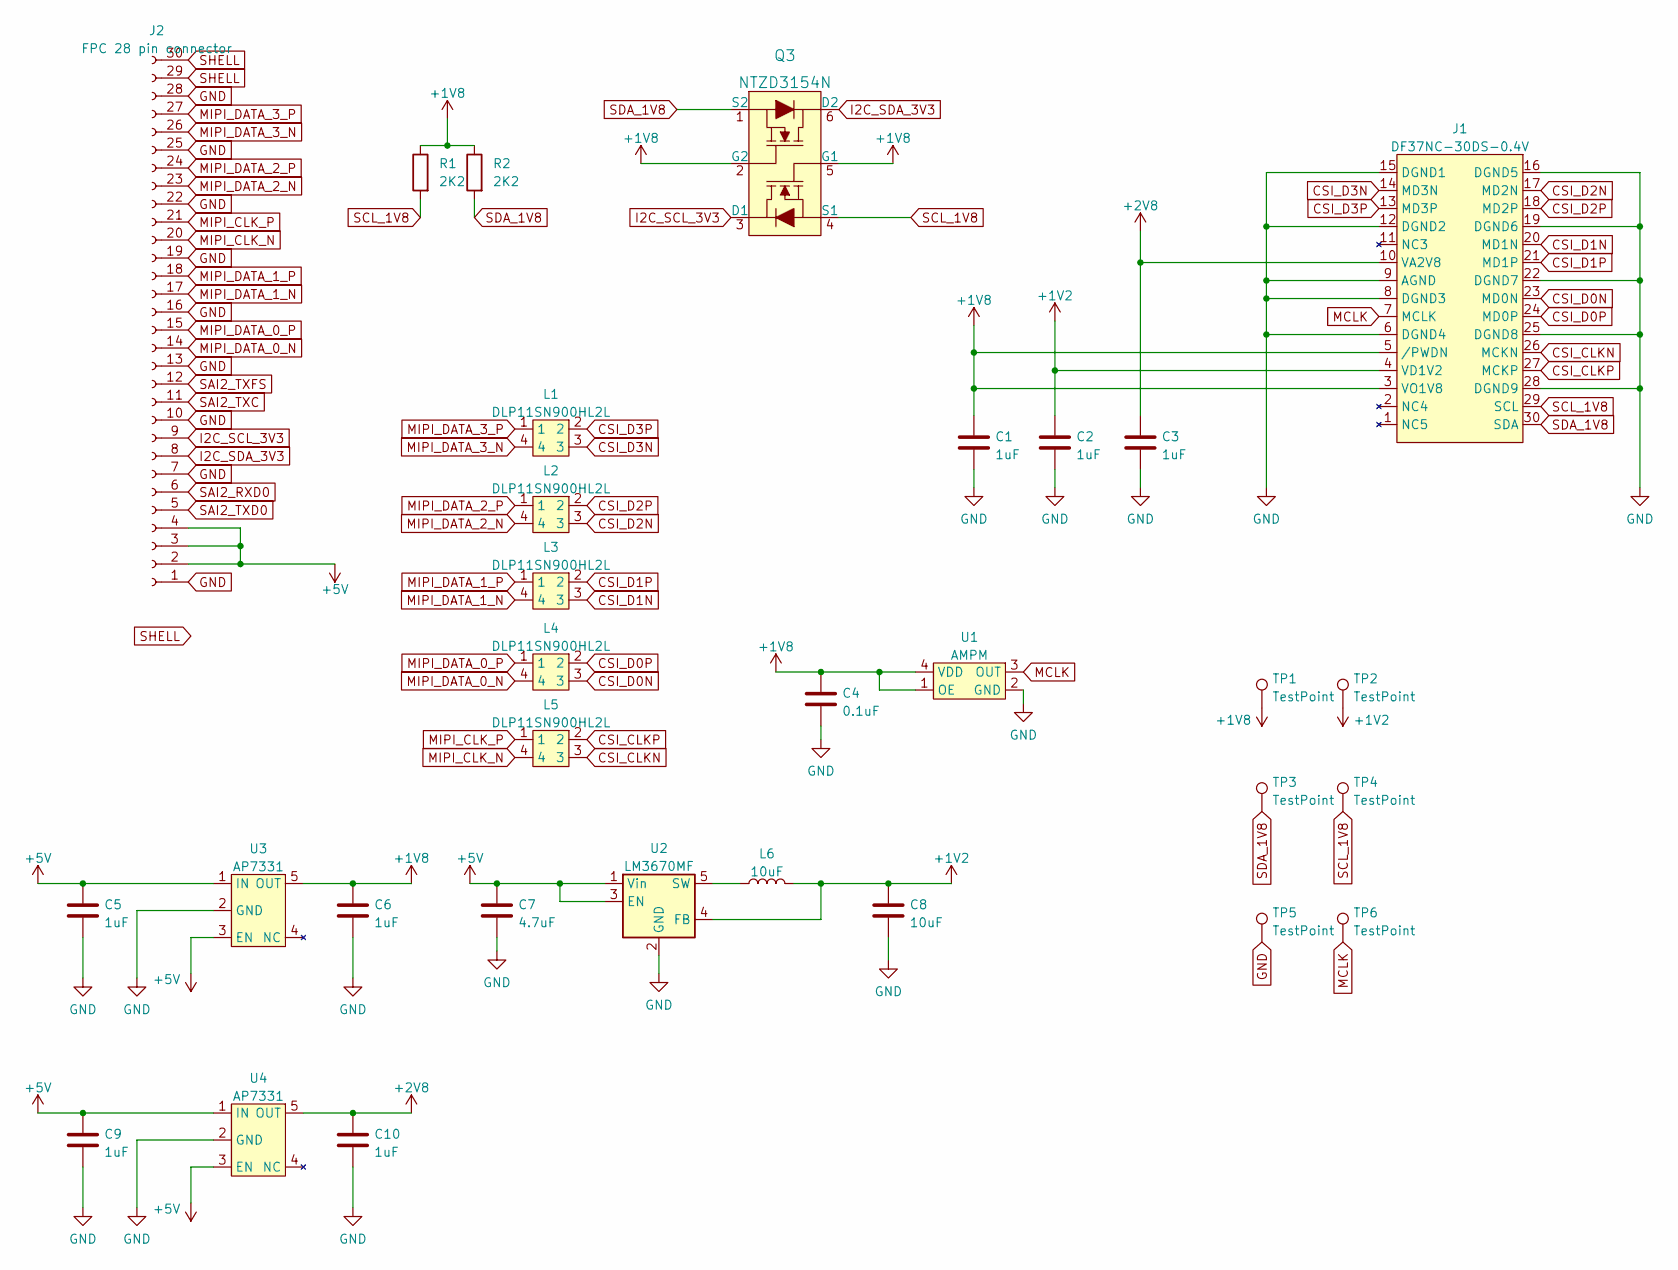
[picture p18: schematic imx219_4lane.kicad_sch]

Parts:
C1, C2, C3, C5, C6, C9, C10: 1uF; C_0603_1608Metric
C4: 0.1uF; C_0603_1608Metric
C7: 4.7uF; C_0603_1608Metric
C8: 10uF; C_0603_1608Metric
J1: DF37NC-30DS-0.4V; DF37NC-30DS
J2: FPC 28 pin connector; Molex 505110-2891
L1, L2, L3, L4, L5: DLP11SN900HL2L; DLP11SN900HL2L_hand_solder
L6: 10uF; C_0603_1608Metric
Q3: NTZD3154N; SOT-563; MPN 2N7002DW-7-F; Digi-Key_PN 2N7002DW-FDICT-ND
R1, R2: 2K2; R_0603_1608Metric
TP1, TP2, TP3, TP4, TP5, TP6: TestPoint; TestPoint_Pad_D0.7mm
U1: AMPM; AMPM oscillator
U2: LM3670MF; SOT-23-5
U3, U4: AP7331; SOT-23-5

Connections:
+1V2: C2.1, C8.1, J1.4 (VD1V2), L6.1, TP2.1, U2.4 (FB)
+1V8: C1.1, C4.1, C6.1, J1.3 (VO1V8), J1.5 (/PWDN), Q3.2 (G2), Q3.5 (G1), R1.1, R2.1, TP1.1, U1.1 (OE), U1.4 (VDD), U3.5 (OUT)
+2V8: C3.1, C10.1, J1.10 (VA2V8), U4.5 (OUT)
+5V: C5.1, C7.1, C9.1, J2.2, J2.3, J2.4, U2.1 (Vin), U2.3 (EN), U3.1 (IN), U3.3 (EN), U4.1 (IN), U4.3 (EN)
CSI_CLKN: J1.26 (MCKN), L5.3
CSI_CLKP: J1.27 (MCKP), L5.2
CSI_D0N: J1.23 (MD0N), L4.3
CSI_D0P: J1.24 (MD0P), L4.2
CSI_D1N: J1.20 (MD1N), L3.3
CSI_D1P: J1.21 (MD1P), L3.2
CSI_D2N: J1.17 (MD2N), L2.3
CSI_D2P: J1.18 (MD2P), L2.2
CSI_D3N: J1.14 (MD3N), L1.3
CSI_D3P: J1.13 (MD3P), L1.2
GND: C1.2, C2.2, C3.2, C4.2, C5.2, C6.2, C7.2, C8.2, C9.2, C10.2, J1.6 (DGND4), J1.8 (DGND3), J1.9 (AGND), J1.12 (DGND2), J1.15 (DGND1), J1.16 (DGND5), J1.19 (DGND6), J1.22 (DGND7), J1.25 (DGND8), J1.28 (DGND9), J2.1, J2.7, J2.10, J2.13, J2.16, J2.19, J2.22, J2.25, J2.28, TP5.1, U1.2 (GND), U2.2 (GND), U3.2 (GND), U4.2 (GND)
I2C_SCL_3V3: J2.9, Q3.3 (D1)
I2C_SDA_3V3: J2.8, Q3.6 (D2)
MCLK: J1.7 (MCLK), TP6.1, U1.3 (OUT)
MIPI_CLK_N: J2.20, L5.4
MIPI_CLK_P: J2.21, L5.1
MIPI_DATA_0_N: J2.14, L4.4
MIPI_DATA_0_P: J2.15, L4.1
MIPI_DATA_1_N: J2.17, L3.4
MIPI_DATA_1_P: J2.18, L3.1
MIPI_DATA_2_N: J2.23, L2.4
MIPI_DATA_2_P: J2.24, L2.1
MIPI_DATA_3_N: J2.26, L1.4
MIPI_DATA_3_P: J2.27, L1.1
unnamed: L6.2, U2.5 (SW)
SAI2_RXD0: J2.6
SAI2_TXC: J2.11
SAI2_TXD0: J2.5
SAI2_TXFS: J2.12
SCL_1V8: J1.29 (SCL), Q3.4 (S1), R1.2, TP4.1
SDA_1V8: J1.30 (SDA), Q3.1 (S2), R2.2, TP3.1
SHELL: J2.29, J2.30

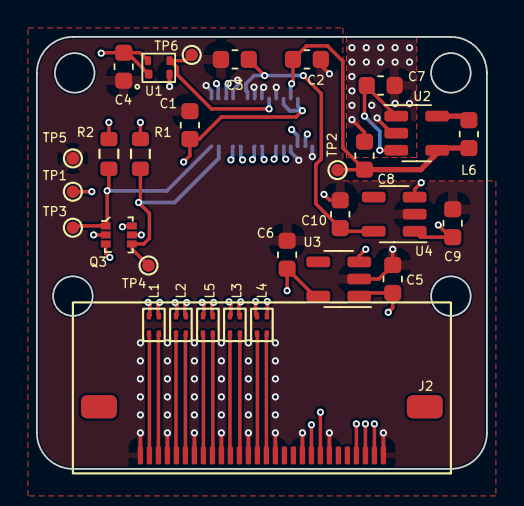
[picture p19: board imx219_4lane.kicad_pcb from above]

Board: 4 copper layers, 25.0 x 24.0 mm, 31 parts (1 on the bottom side), 32 nets.

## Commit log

2026-03-12 rework directory structure
    [imx219_4lane.kicad_pcb, imx219_4lane.kicad_sch]
2026-03-12 add arducam IMX219_fisheye model
    [IMX219_fisheye.FCStd, imx219_4lane.kicad_pcb, imx219_4lane.kicad_sch]
2026-03-13 preliminary 3d placements
    [IMX219_fisheye.FCStd, IMX219_fisheye.stl, camera.FCStd]
2026-03-14 update SoM model
    [camera.FCStd]
2026-04-10 new IMX678 model
    [camera.FCStd]
2026-04-18 initial part selection in schematic
    [camera.FCStd, mainboard.kicad_pcb, mainboard.kicad_sch]
2026-04-19 TPS61235 stable 5V schematic
    [mainboard.kicad_sch]
2026-04-20 preliminary BQ25601D
    [mainboard.kicad_sch]
2026-04-27 start MIPI adaption from SOM board
    [mainboard.kicad_sch]
2026-04-28 added board to board connections for SOM
    [mainboard.kicad_sch]
2026-04-29 add accelerometer + magnetometer default schematic
    [mainboard.kicad_sch]
2026-04-30 preliminary FPC MIPI conn from SOM
    [mainboard.kicad_sch]
2026-05-01 split cam connections + rotate b2b connectors
    [mainboard.kicad_sch]
2026-05-02 place board to board connectors
    [mainboard.kicad_pcb]
2026-05-02 switch b2b connector order
    [mainboard.kicad_sch]
2026-05-04 USB PD AP33771C
    [mainboard.kicad_pcb, mainboard.kicad_sch]
2026-05-06 increase pagesize, rework power ICs
    [mainboard.kicad_sch]
2026-05-06 rework battery charger
    [mainboard.kicad_sch]
2026-05-06 GNSS level shifters, corect labels, set CHG voltage + current
    [mainboard.kicad_sch]
2026-05-06 testpoints, GNSS backup from sparkfun
    [mainboard.kicad_sch]
2026-05-06 update b2b connector labels
    [mainboard.kicad_sch]
2026-05-07 update docs
    [mainboard.kicad_sch]
2026-05-07 update 3d model
    [camera.FCStd]
2026-05-07 FTDI IC to USB conn
    [mainboard.kicad_sch]
2026-05-08 add SD card + separate 3V3 for GNSS IC
    [mainboard.kicad_sch]
2026-05-08 SD pt. II
    [mainboard.kicad_sch]
2026-05-09 TP all the things!
    [mainboard.kicad_sch]
2026-05-09 PCB stackup
    [mainboard.kicad_pcb]
2026-05-09 update with created footprints
    [mainboard.kicad_sch]
2026-05-09 updated battery holder for GNSS backup power
    [mainboard.kicad_pcb, mainboard.kicad_sch]
2026-05-09 add schematic as PDF
2026-05-10 rough grouping of ICs on PCB
    [camera.FCStd, mainboard.kicad_pcb, mainboard.kicad_sch]
2026-05-11 assign 3D models
    [camera.FCStd, mainboard.kicad_pcb]
2026-05-11 parts placement
    [camera.FCStd, mainboard.kicad_pcb, mainboard.kicad_sch]
2026-05-12 preliminary placement of all parts
    [mainboard.kicad_pcb, mainboard.kicad_sch]
2026-05-13 replace battery with dual 18350
    [mainboard.kicad_pcb, mainboard.kicad_sch]
2026-05-13 organize PCB around new battery holder
    [mainboard.kicad_pcb, mainboard.kicad_sch]
2026-05-13 replace FTDI with DFN12 package
    [mainboard.kicad_pcb, mainboard.kicad_sch]
2026-05-15 update active antenna design
    [mainboard.kicad_pcb, mainboard.kicad_sch]
2026-05-21 update SMA receptable
    [mainboard.kicad_pcb, mainboard.kicad_sch]
2026-05-27 update to KiCad v10.0
    [mainboard.kicad_pcb, mainboard.kicad_sch]
2026-05-27 switch to vertical USB C receptable for shell
    [mainboard.kicad_pcb, mainboard.kicad_sch]
2026-05-27 length match cam0 pairs
    [mainboard.kicad_pcb]
2026-05-27 USB PD power
    [mainboard.kicad_pcb]
2026-05-28 BQ25606 routing
    [mainboard.kicad_pcb, mainboard.kicad_sch]
2026-05-29 TPS61235p 5v PWR routing
    [mainboard.kicad_pcb, mainboard.kicad_sch]
2026-05-31 route ublox GNSS receiver
    [mainboard.kicad_pcb, mainboard.kicad_sch]
2026-06-03 change MIPI CSI location according to new schematics
    [mainboard.kicad_sch]
2026-06-04 new 3V3 setup for cameras, 30 pin mipi connections
    [mainboard.kicad_pcb, mainboard.kicad_sch]
2026-06-04 place ment of new 3V3 + oscillators + reset mechanic
    [mainboard.kicad_pcb, mainboard.kicad_sch]
2026-06-05 placeholder osci 3d shape
    [mainboard.kicad_pcb]
2026-06-05 cam1 MIPI pairs
    [mainboard.kicad_pcb, mainboard.kicad_sch]
2026-06-05 cam0 MIPI pairs
    [mainboard.kicad_pcb, mainboard.kicad_sch]
2026-06-06 dead reckoning routing
    [mainboard.kicad_pcb, mainboard.kicad_sch]
2026-06-06 SD card routing
    [mainboard.kicad_pcb, mainboard.kicad_sch]
2026-06-06 I2C cam0 cam1
    [mainboard.kicad_pcb, mainboard.kicad_sch]
2026-06-08 route TPs
    [mainboard.kicad_pcb, mainboard.kicad_sch]
2026-06-08 update schematic PDF
2026-06-09 zone fill clearance
    [mainboard.kicad_pcb]
2026-06-09 correct terminal USB pads
    [mainboard.kicad_pcb]
2026-06-09 silkscreen readability check
    [mainboard.kicad_pcb]
2026-06-09 5V connection to DF40
    [mainboard.kicad_pcb, mainboard.kicad_sch]
2026-06-09 fix drill sizes + add GND vias
    [mainboard.kicad_pcb, mainboard.kicad_sch]
2026-06-10 back silkscreen readability
    [mainboard.kicad_pcb]
2026-06-10 add on-off slider switch
    [mainboard.kicad_pcb, mainboard.kicad_sch]
2026-06-10 create HAILO SOM mounting holes
    [mainboard.kicad_pcb, mainboard.step]
2026-06-10 update 3D model + add preview to docs
    [camera.FCStd]
2026-06-10 improve schematic readability + add docstrings
    [mainboard.kicad_sch]
2026-06-15 fix schematic PDF location
2026-06-23 start 3d work on case
    [camera-mainboard.stl, camera.FCStd]
2026-08-05 add 3D model for FTDI chip
    [mainboard.kicad_pcb]
